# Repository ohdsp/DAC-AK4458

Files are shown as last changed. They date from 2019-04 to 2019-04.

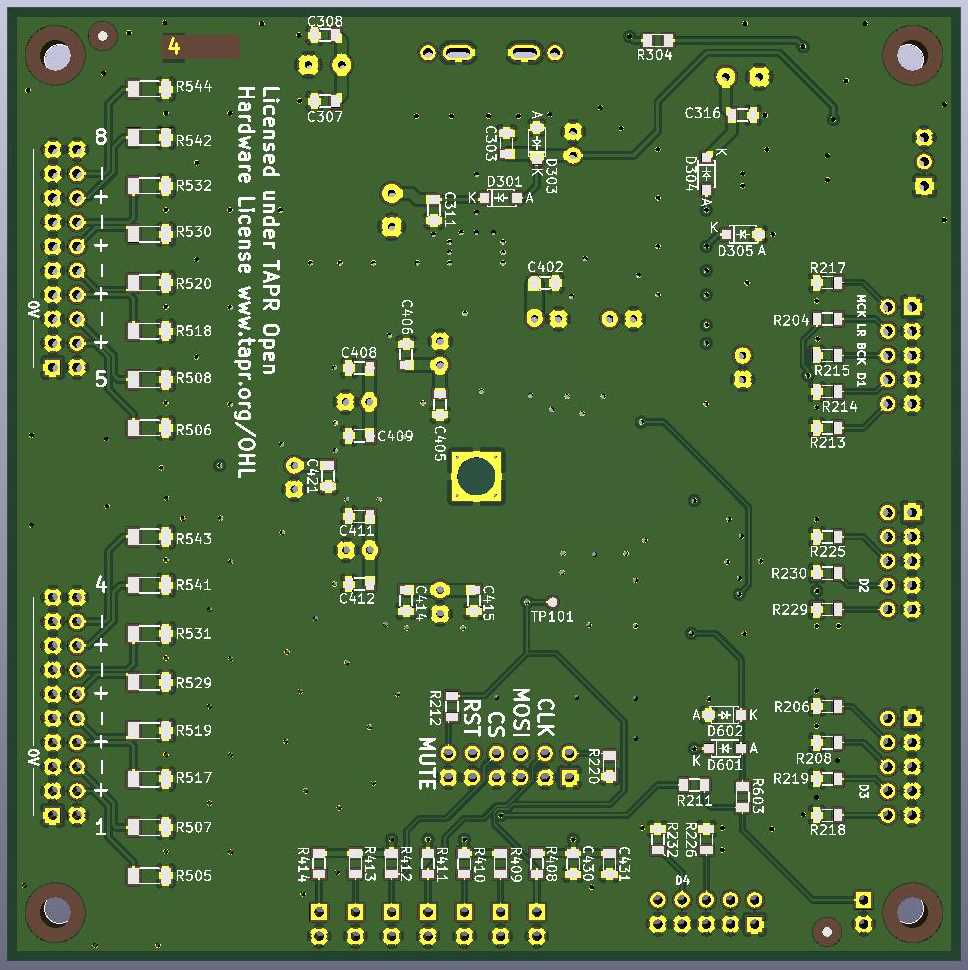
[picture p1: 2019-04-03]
JPEGs/DAC-AK4458-1.0-Bottom-small.jpg

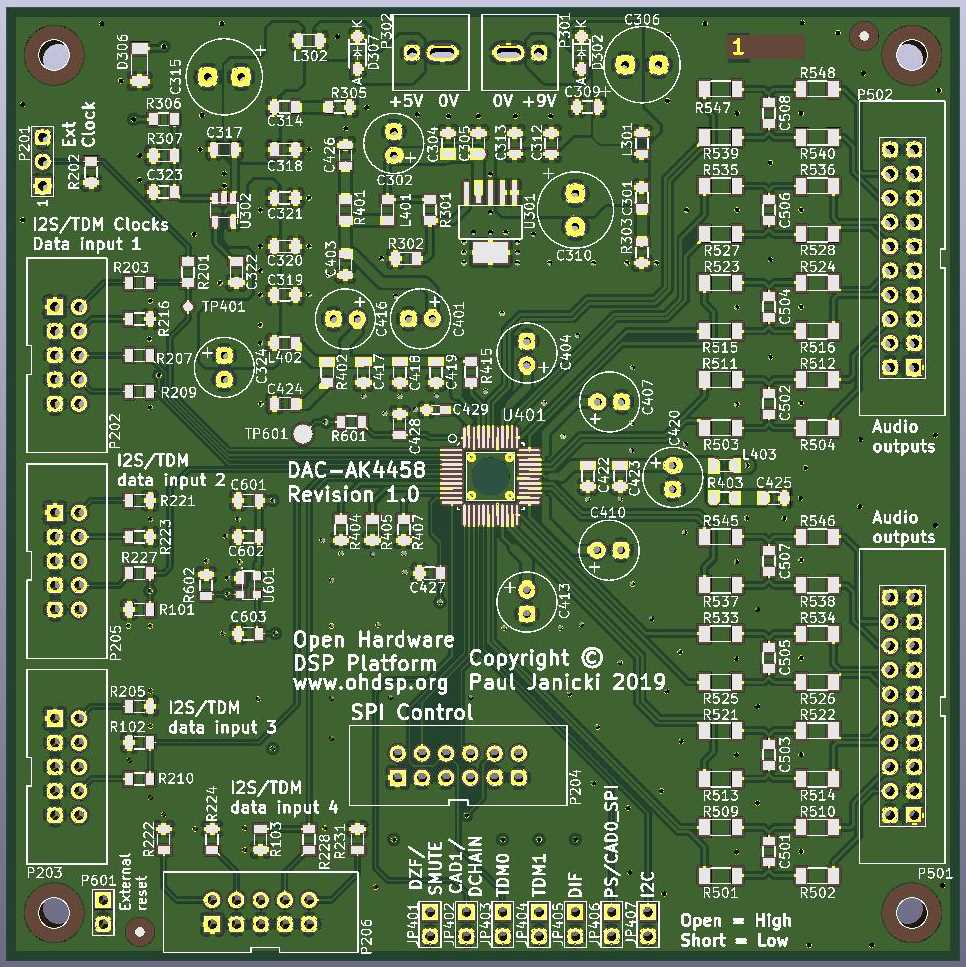
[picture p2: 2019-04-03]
JPEGs/DAC-AK4458-1.0-Front-small.jpg

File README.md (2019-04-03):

# [Open Hardware DSP Platform](http://www.ohdsp.org)
## DAC-AK4458
### Revision 1.0
### 8 Differential DAC Output Board

---
# README
### Disclaimer
Copyright Paul Janicki 2019

Licensed under the TAPR Open Hardware License (www.tapr.org/OHL)

This documentation is distributed WITHOUT ANY EXPRESS OR IMPLIED WARRANTY, INCLUDING OF MERCHANTABILITY, SATISFACTORY QUALITY AND FITNESS FOR A PARTICULAR PURPOSE.

### What is this repository?

**Quick summary**

This is Open Hardware DSP Platform DAC-AK4458 Revision 1.0. 

This is an 8 differential outputb DAC board based on the AK4458.

This repository contains the KiCad design files, manufacturing Gerber/drill files, PDF/drawing files, and relevant documenation for this board.

### What is the project folder structure?
Most folder names are self explanatory. Starting from the top level: \
*DAC-AK4458*
+ *Bill of Materials*  - This contains the bill of materials in CVS, LibreOffice Calc and XML formats
+ *Drawings* - This contains PDF and SVG Schematic and PCB files
+ *Gerbers* - This contains the PCB Gerbers and drill drawings for manufacture, there is also a zip file ready to send to most manufacturers
+ *JPEGs* - JPEGs of top and bottom views from 3D viewer
+ *KiCad* - This contains the original KiCad schematic and PCB design files
+ *Pick and Place* - This contains pick and place files for top and bottom sides
### How do I get set up?

**Summary of set up**

1. Set your self up a directory on a local disk, something simple will make life easier (eg C:\Electronics on Windows as used here), but anywhere will do just fine.
2. Download the Kicad-Libs from [https://github.com/ohdsp/KiCad-Libs](https://github.com/ohdsp/KiCad-Libs) and place in C:\Electronics\Kicad-Libs (or your chosen folder) 
3. Create a OHDSP subdirectory in C:\Electronics (so C:\Electronics\OHDSP)
3. Download this project to C:\Electronics\OHDSP\DAC-AK4458
4. Fire up Kicad
5. Open the main project file C:\Electronics\OHDSP\DAC-AK4458\KiCad\DAC-AK4458-1.0.pro
7. Do as you wish with the project, just keep it under the TAPR Open Hardware License.
Note: For library issues see below.

Make sure your git setup doesn't exclude files used in the project (like .LIB files) or things may go wrong down the line.

**KiCad Library Configuration**

Note that libraries are setup using relative paths, if you follow the above instructions things should work just fine. Below is the default library setup.

To setup eeschema component libraries:
From KiCad main window go to menu Tools -> Edit Schematic Symbols. In the new Window go to menu Preferences -> Manage Symbol Libraries.

On the new "Symbol Libraries" window select the "Project Specific Libraries" tab. The "Append Library" and "Remove Library" buttons can be used to add/remove enteries.
The standard setup is:

| | Active | Nickname | Library Path | Plugin Type | Options | Description |
|---|---|---|---|---|---|---|
| 1 | Ticked | power | ${KICAD_SYMBOL_DIR}/power.lib | Legacy | (blank) | (blank) |
| 2 | Ticked | MyKiCadLibs-Lib | ${KIPRJMOD}/../../../KiCad-Libs/MyKiCadLibs-Lib.lib | Legacy | (blank) | (blank) |

${KICAD_SYMBOL_DIR}  is set under the Enviromnet Variable Configuration. Close Symbol Libraries dialogue and go "Preferences" -> "Configure Paths..."

${KICAD_SYMBOL_DIR} is set to C:\Program Files\KiCad\share\kicad\library - this is the default for a KiCad install on the C drive

${KIPRJMOD} is automatically set to the location of the project (.pro file), in this example this would be C:\Electronics\OHDSP\uDSP\KiCad

To setup Pcbnew libraries:
From KiCad main window go to menu Tools -> Edit PCB Footprints. In the new Window go to menu Preferences -> Manage Symbol Libraries.

On the new "Symbol Libraries" window select the "Project Specific Libraries" tab. The "Append Library" and "Remove Library" buttons can be used to add/remove enteries.
The standard setup is:

| | Active | Nickname | Library Path | Plugin Type | Options | Description |
|---|---|---|---|---|---|---|
| 1 | Ticked | MyKiCadLibs-Footprints | ${KIPRJMOD}/../../../KiCad-Libs/MyKiCadLibs-Footprints.pretty | KiCad | (blank) | (blank) |

${KIPRJMOD} is automatically set to the location of the project (.pro file), in this example this would be C:\Electronics\OHDSP\uDSP\KiCad

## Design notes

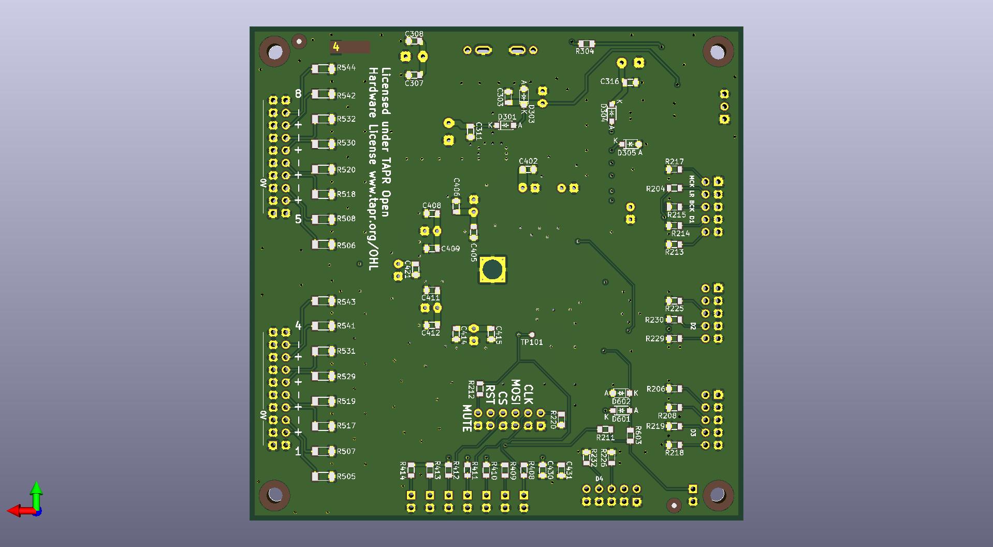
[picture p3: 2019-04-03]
JPEGs/DAC-AK4458-1.0-Bottom.jpg

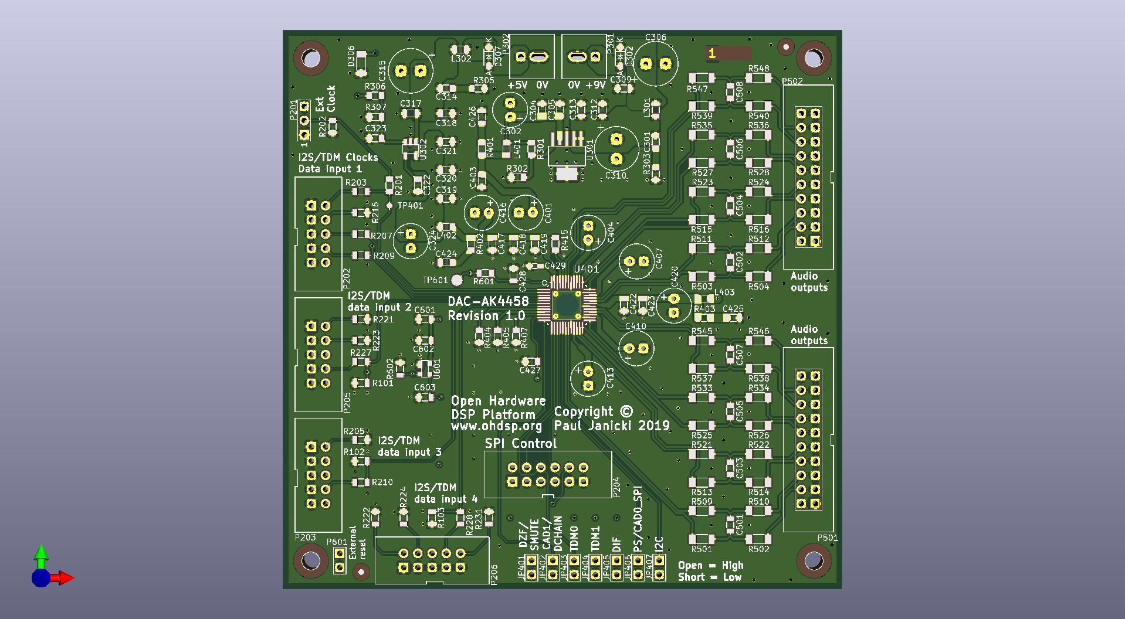
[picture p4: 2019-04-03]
JPEGs/DAC-AK4458-1.0-Front.jpg

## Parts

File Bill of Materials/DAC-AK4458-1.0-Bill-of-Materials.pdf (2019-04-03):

DAC-AK4458-1.0 Bill of Materials

### DAC-AK4458-1.0 Bill of Materials 03 April 2019

Reference | Quantity | Footprint | Value | Description | Power | Size | Tolerance Voltage | | Type | Current
C301 C314 C424 C425 C426 | 5 SMD-0805 | | 100p | 'Ceramic capacitor | ' | '0805 | '5% | '50V | 'C0G | '
C302 C324 C401 C416 C420 | 5 CAP-TH-D6.3mmP2.5mm | | 220u | 'Aluminium electrolytic low impedance capacitor - eg Panasonic FC or FR parts | ' | '2.5mm Pitch, 6.3mm Diameter | ' | '10V | ' | '
C306 C310 C315 | 3 CAP-TH-D8mmP3.5mm | | 220u | 'Aluminium electrolytic low impedance capacitor - eg Panasonic FC or FR parts | ' | '3.5mm Pitch, 8mm Diameter | ' | '25V | ' | '
C307 C311 C316 | 3 SMD-0805 | | 22u | 'Ceramic capacitor | ' | '0805 | '20% | '25V | 'X5R | '
C304 C308 C312 C317 C320 C323 C403 C405 C408 C411 C414 C418 C422 C428 C430 C602 | 16 SMD-0805 | | 100n | 'Ceramic capacitor | ' | '0805 | '10% | '50V | 'X7R | '
C305 C309 C313 C318 C321 C406 C409 C412 C415 C419 C423 C427 C603 | 13 SMD-0805 | | 10n | 'Ceramic capacitor | ' | '0805 | '10% | '50V | 'X7R | '
C303 C319 C402 C417 C421 | 5 SMD-0805 | | 22u | 'Ceramic capacitor | ' | '0805 | '20% | '10V | 'X5R | '
C322 | 1 SMD-0805 | | N/F | 'Ceramic capacitor - NOT FITTED | ' | '0805 | '10% | '50V | 'X7R | '
C404 C407 C410 C413 | 4 CAP-TH-D6.3mmP2.5mm | | 47u | 'Aluminium electrolytic low impedance capacitor - eg Panasonic FC or FR parts | ' | '2.5mm Pitch, 6.3mm Diameter | ' | '10V | ' | '
C429 | 1 SMD-0603 | | 1u | 'Ceramic capacitor | ' | '0603 | '10% | '10V | 'X7R | '
C431 C601 | 2 SMD-0805 | | 10u | 'Ceramic capacitor | ' | '0805 | '20% | '10V | 'X5R | '
C501 C502 C503 C504 C505 C506 C507 C508 | 8 SMD-0805 | | 2n7 | 'Ceramic capacitor | ' | '0805 | '5% | '50V | 'C0G | '
D301 D302 D303 D304 D305 D307 D601 D602 | 8 DIODE-SOD-123 | | 1N5819HW | '1A 40V Schottky Rectifier - SOD-123 | ' | ' | ' | ' | ' | '
D306 | 1 SMD-1206 | | Green LED 1206 | 'Green LED - SMD - Vf 1.8V to 2.2V | ' | '1206 | ' | ' | ' | '
JP401 JP402 JP403 JP404 JP405 JP406 JP407 P601 | 8 CONN_SIL_2_1MM | | CONN_2x1 | '1x2 2.54mm pitch pin header | ' | ' | ' | ' | ' | '
L301 L302 L401 L402 L403 | 5 SMD-0805 | | 600R@100MHz | 'Ferrite bead, current rating 0.3A or higher, 600R@100MHz | ' | '0805 | ' | ' | ' | '=>0.3A
P201 | 1 CONN_SIL_3_1MM | | CONN_3x1 | '1x3 2.54mm pitch pin header | ' | ' | ' | ' | ' | '
P202 P203 P205 P206 | 4 CONN_DIL_2X5_BOX_1MM | | CONN_02X05 | '2x5 2.54mm pitch box header | ' | ' | ' | ' | ' | '
P204 | 1 CONN_DIL_2X6_BOX_1MM | | CONN_02X06 | '2x6 2.54mm pitch box header | ' | ' | ' | ' | ' | '
P301 P302 | 2 CONN-2WAY-2.54mm-3.81mm-SPACING | | CONN_2x1 | '2 way screw terminal, 2.54mm to 3.81mm pitch | ' | ' | ' | ' | ' | '
P501 P502 | 2 CONN_DIL_2X10_BOX_1MM | | CONN_02X10 | '2x10 2.54mm pitch box header | ' | ' | ' | ' | ' | '
R101 R102 R103 R213 R218 R220 R229 R231 R304 R603 | 10 SMD-0805 | | 1k | 'Thick or thin film resistor | '100mW | '0805 | '1% | ' | ' | '
R201 R202 R214 R215 R216 R217 R219 R230 R232 | 9 SMD-0805 | | N/F | 'Thick or thin film resistor | '100mW | '0805 | '1% | ' | ' | '
R203 R204 R207 R209 R210 R211 R212 R227 R228 R404 R405 R407 R415 | 13 SMD-0805 | | 0 | 'Thick or thin film resistor | '100mW | '0805 | '1% | ' | ' | '
R205 R206 R208 R221 R222 R223 R224 R225 R226 R408 R409 R410 R411 R412 R413 R414 | 16 SMD-0805 | | 10k | 'Thick or thin film resistor | '100mW | '0805 | '1% | ' | ' | '
R301 | 1 SMD-0805 | | 6k8 | 'Thick or thin film resistor | '100mW | '0805 | '1% | ' | ' | '
R302 | 1 SMD-0805 | | 2k2 | 'Thick or thin film resistor | '100mW | '0805 | '1% | ' | ' | '
R303 R305 R401 R402 R403 | 5 SMD-0805 | | 47 | 'Thick or thin film resistor | '100mW | '0805 | '1% | ' | ' | '
R306 | 1 SMD-0805 | | 10K | 'Thick or thin film resistor | '100mW | '0805 | '1% | ' | ' | '
R307 | 1 SMD-0805 | | 220K | 'Thick or thin film resistor | '100mW | '0805 | '1% | ' | ' | '
R501 R503 R509 R511 R513 R515 R521 R523 R525 R527 R533 R535 R537 R539 R545 R547 | 16 SMD-1206 | | 240 | 'MELF0204 1% =>250mW or 1206 1% =>250mW | '250mW | '1206 | '1% | ' | ' | '
R502 R504 R510 R512 R514 R516 R522 R524 R526 R528 R534 R536 R538 R540 R546 R548 | 16 SMD-1206 | | 100 | 'MELF0204 1% =>250mW or 1206 1% =>250mW | '250mW | '1206 | '1% | ' | ' | '
R505 R506 R507 R508 R517 R518 R519 R520 R529 R530 R531 R532 R541 R542 R543 R544 | 16 SMD-1206 | | 100k | 'MELF0204 1% =>250mW or 1206 1% =>250mW | '250mW | '1206 | '1% | ' | ' | '
R601 | 1 SMD-0805 | | 100 | 'Thick or thin film resistor | '100mW | '0805 | '1% | ' | ' | '
R602 | 1 SMD-0805 | | 100k | 'Thick or thin film resistor | '100mW | '0805 | '1% | ' | ' | '
U301 | 1 IC-SOT223-6 | | TPS7A4501DCQ | 'TI TPS7A4501DCQ Regulator | ' | ' | ' | ' | ' | '
U302 | 1 IC-SOT23-5 | | TLV70033DDC | 'TLV700 200-mA, Low-IQ, Low-Dropout Regulator | ' | ' | ' | ' | ' | '
U401 | 1 IC_QFN_48_5.1mmpad_HF_HS | | AK4458VN | 'AK4458 8ch Premium DAC | ' | ' | ' | ' | ' | '
U601 | 1 IC-SOT143 | | CAT811TTBI | 'CAT811/ADM811 - 4-Pin Microprocessor Power Supply Supervisor with Manual Reset - Active Low | ' | ' | ' | ' | ' | '

Licensed under the TAPR Open Hardware License (www.tapr.org/OHL)

Open Hardware DSP Platform www.ohdsp.org

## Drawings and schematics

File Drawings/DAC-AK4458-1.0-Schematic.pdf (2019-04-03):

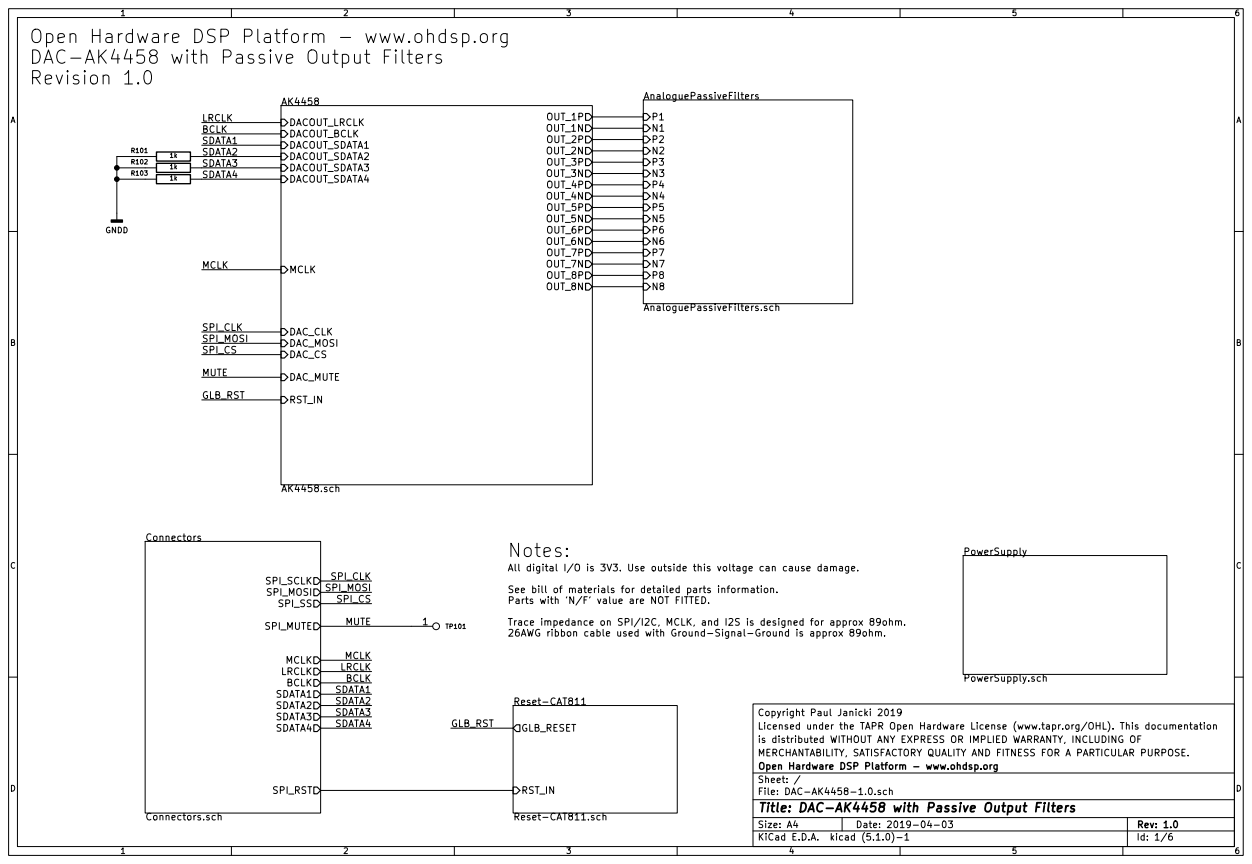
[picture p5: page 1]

AnaloguePassiveFilters.sch P1N1P2N2P3N3P4N4P5N5P6N6P7N7P8N8 Open Hardware DSP Platform - www.ohdsp.org
DAC-AK4458 with Passive Output Filters
Revision 1.0

All digital I/O is 3V3. Use outside this voltage can cause damage.

See bill of materials for detailed parts information.
Parts with 'N/F' value are NOT FITTED.

Trace impedance on SPI/I2C, MCLK, and I2S is designed for approx 89ohm.
26AWG ribbon cable used with Ground-Signal-Ground is approx 89ohm.

Copyright Paul Janicki 2019
Licensed under the TAPR Open Hardware License (www.tapr.org/OHL). This documentation
is distributed WITHOUT ANY EXPRESS OR IMPLIED WARRANTY, INCLUDING OF
MERCHANTABILITY, SATISFACTORY QUALITY AND FITNESS FOR A PARTICULAR PURPOSE.
File: DAC-AK4458-1.0.sch Sheet: / Open Hardware DSP Platform - www.ohdsp.org

Id: 1/6 Title: DAC-AK4458 with Passive Output Filters

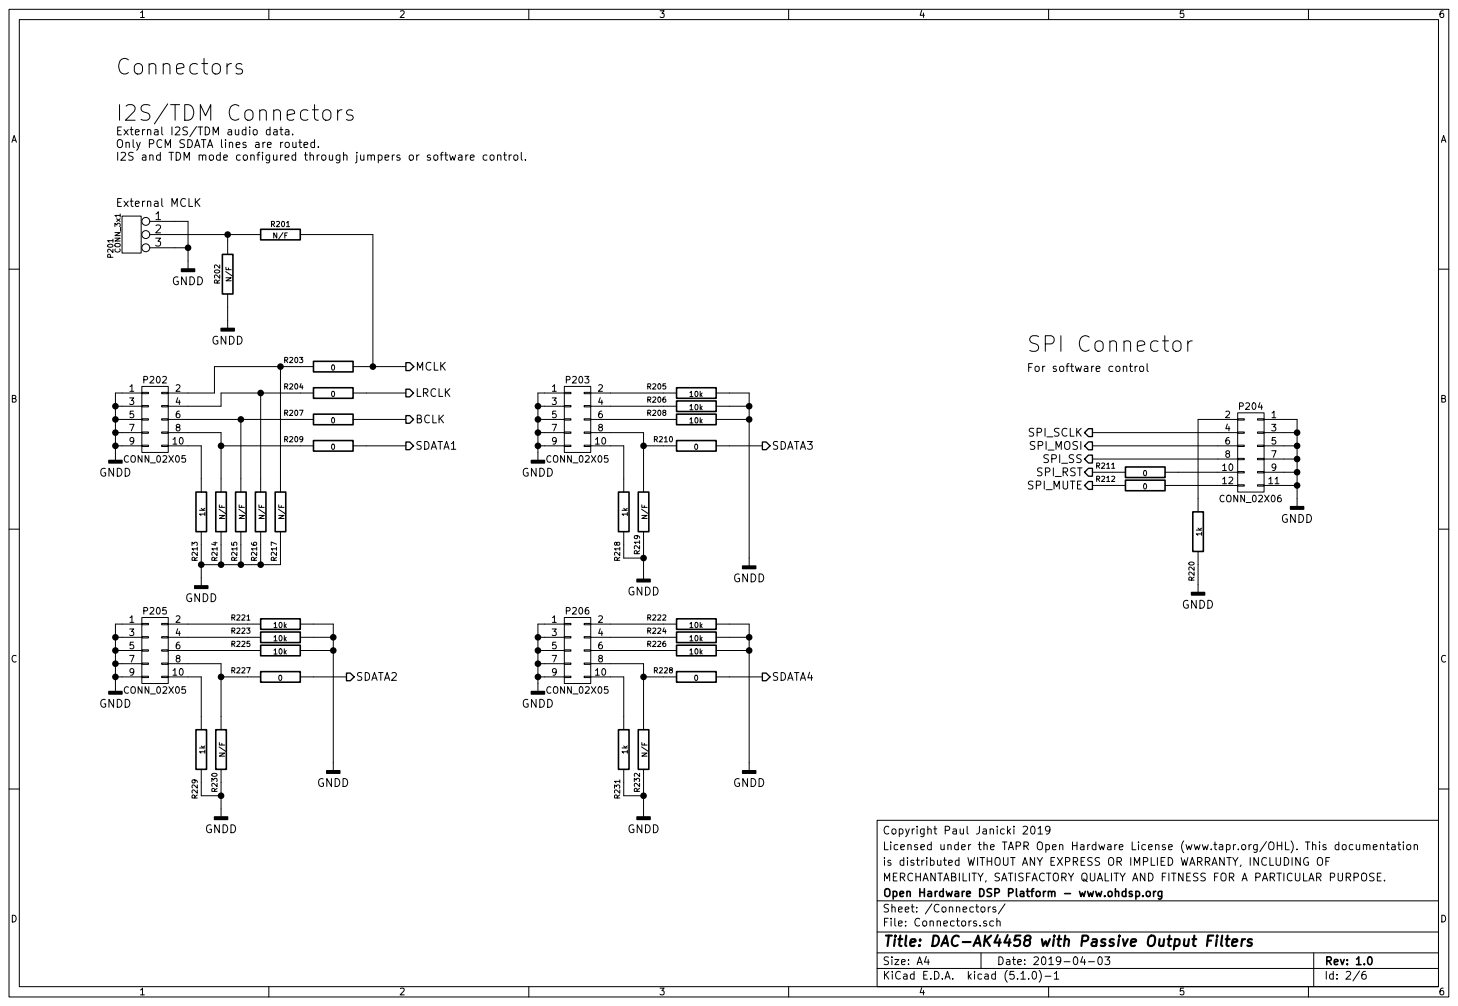
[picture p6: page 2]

I2S/TDM Connectors
External I2S/TDM audio data.
Only PCM SDATA lines are routed.
I2S and TDM mode configured through jumpers or software control.

Copyright Paul Janicki 2019
Licensed under the TAPR Open Hardware License (www.tapr.org/OHL). This documentation
is distributed WITHOUT ANY EXPRESS OR IMPLIED WARRANTY, INCLUDING OF
MERCHANTABILITY, SATISFACTORY QUALITY AND FITNESS FOR A PARTICULAR PURPOSE.
File: Connectors.sch Sheet: /Connectors/ Open Hardware DSP Platform - www.ohdsp.org

Id: 2/6 Title: DAC-AK4458 with Passive Output Filters

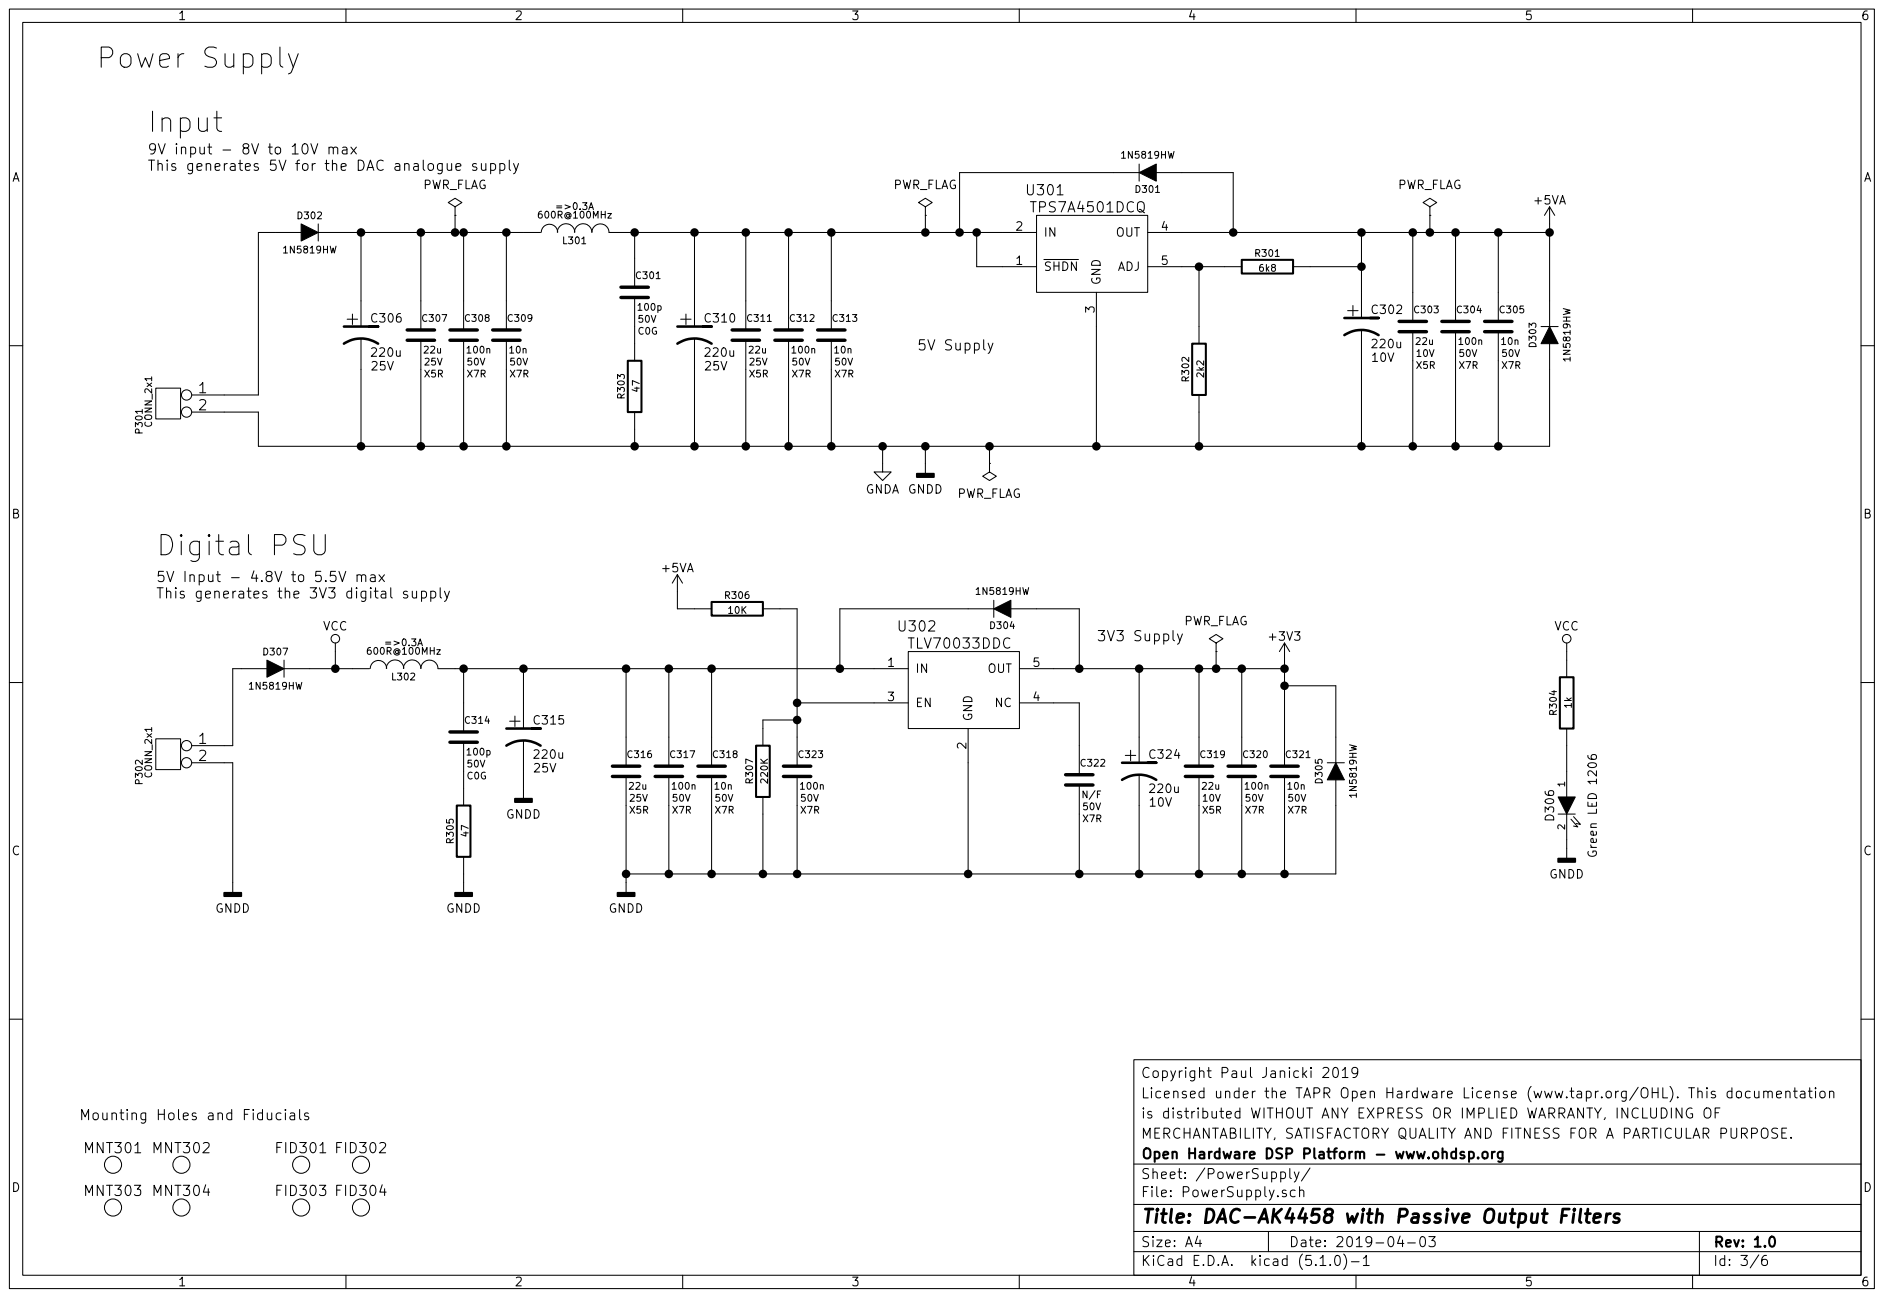
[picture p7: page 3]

9V input - 8V to 10V max
This generates 5V for the DAC analogue supply

Copyright Paul Janicki 2019 GNDA GNDD

5V Input - 4.8V to 5.5V max
This generates the 3V3 digital supply

Licensed under the TAPR Open Hardware License (www.tapr.org/OHL). This documentation
is distributed WITHOUT ANY EXPRESS OR IMPLIED WARRANTY, INCLUDING OF
MERCHANTABILITY, SATISFACTORY QUALITY AND FITNESS FOR A PARTICULAR PURPOSE.
Open Hardware DSP Platform - www.ohdsp.org
Sheet: /PowerSupply/
File: PowerSupply.sch
Id: 3/6 Title: DAC-AK4458 with Passive Output Filters

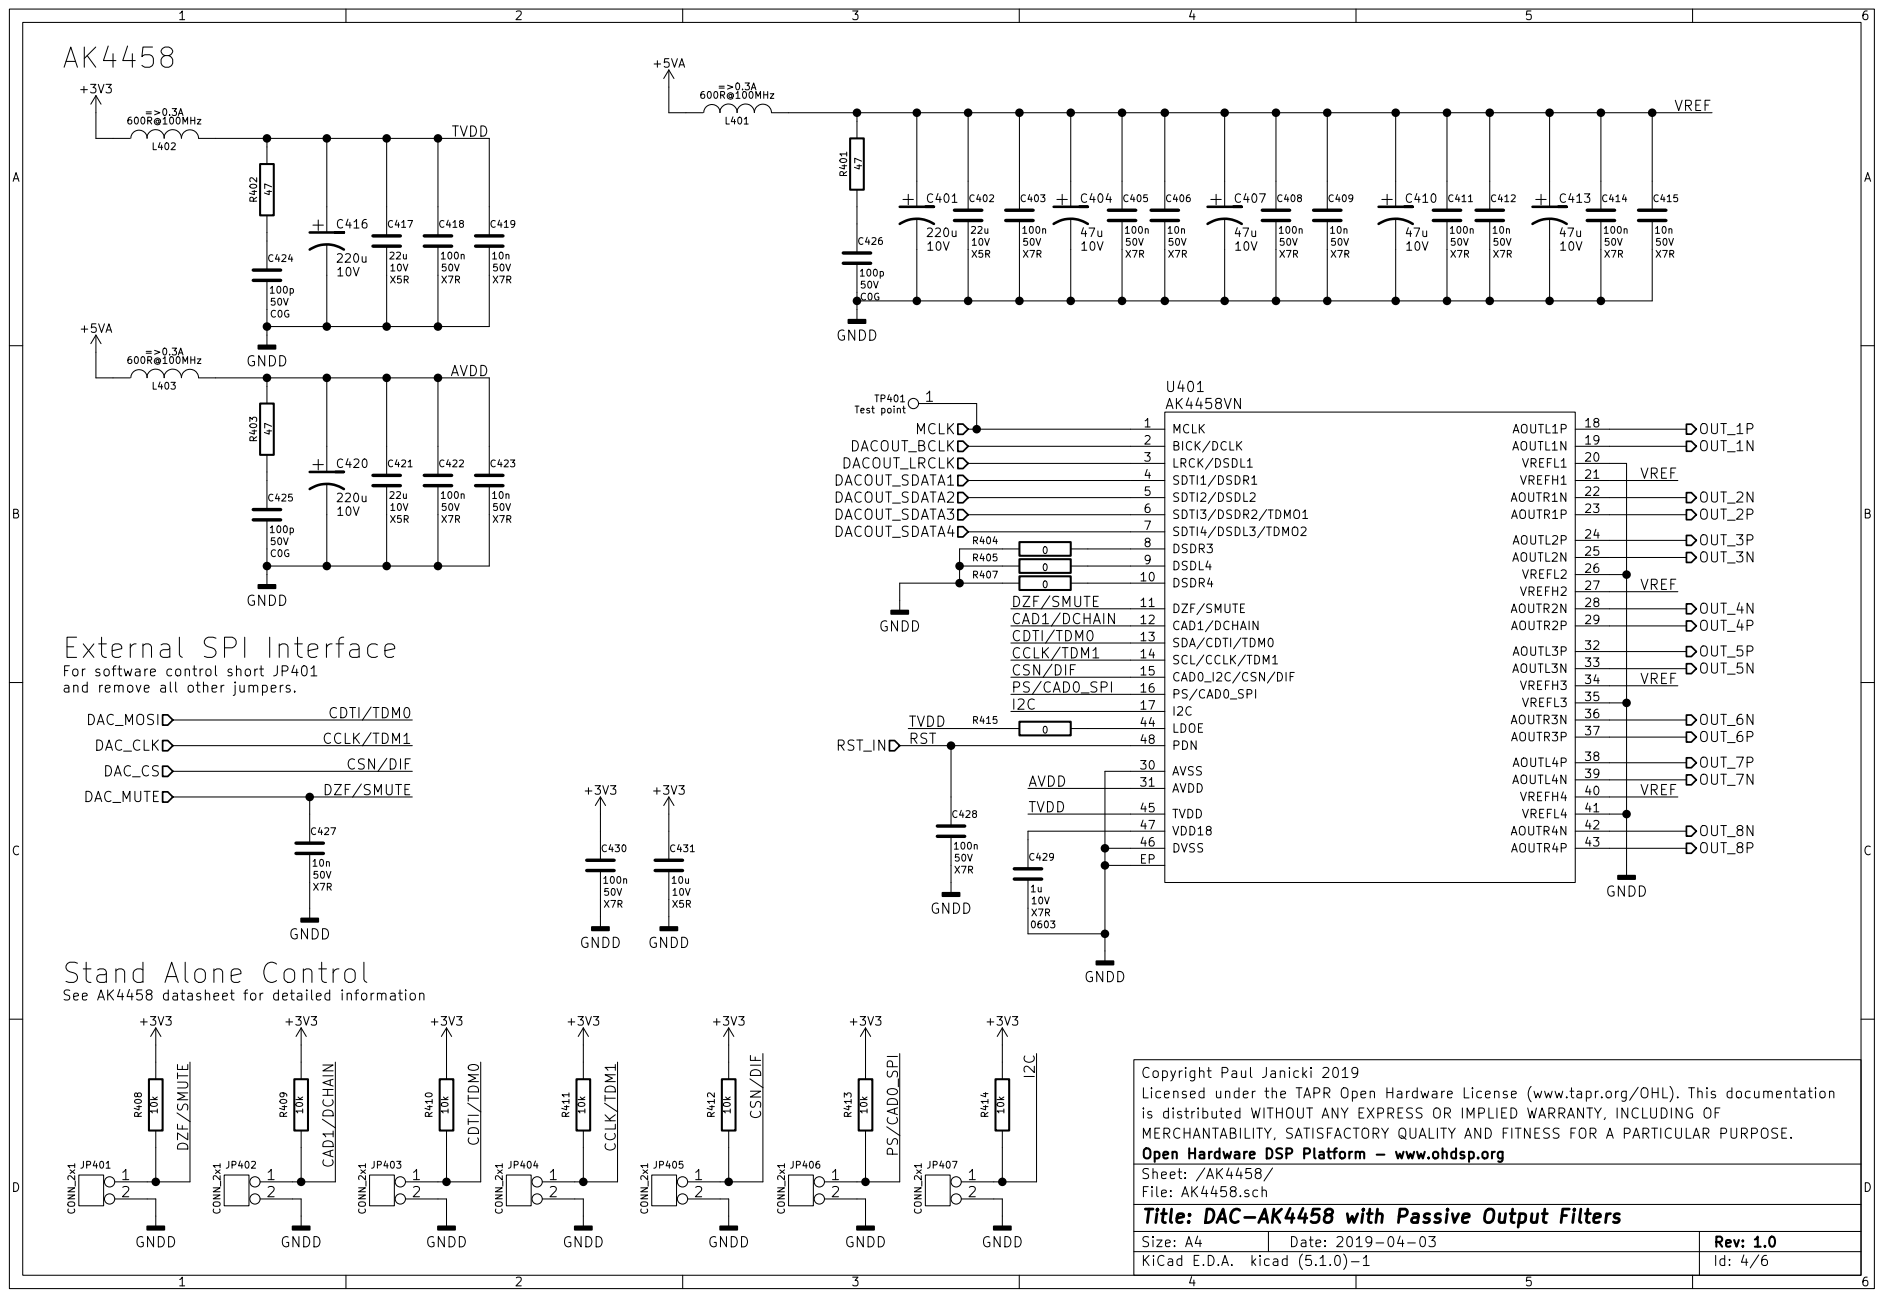
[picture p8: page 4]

VREF External SPI Interface

X7R VREF VREF VREF VREF GNDD

For software control short JP401
and remove all other jumpers.

Copyright Paul Janicki 2019
Licensed under the TAPR Open Hardware License (www.tapr.org/OHL). This documentation
is distributed WITHOUT ANY EXPRESS OR IMPLIED WARRANTY, INCLUDING OF
MERCHANTABILITY, SATISFACTORY QUALITY AND FITNESS FOR A PARTICULAR PURPOSE.
File: AK4458.sch Sheet: /AK4458/ Open Hardware DSP Platform - www.ohdsp.org

Id: 4/6 Title: DAC-AK4458 with Passive Output Filters

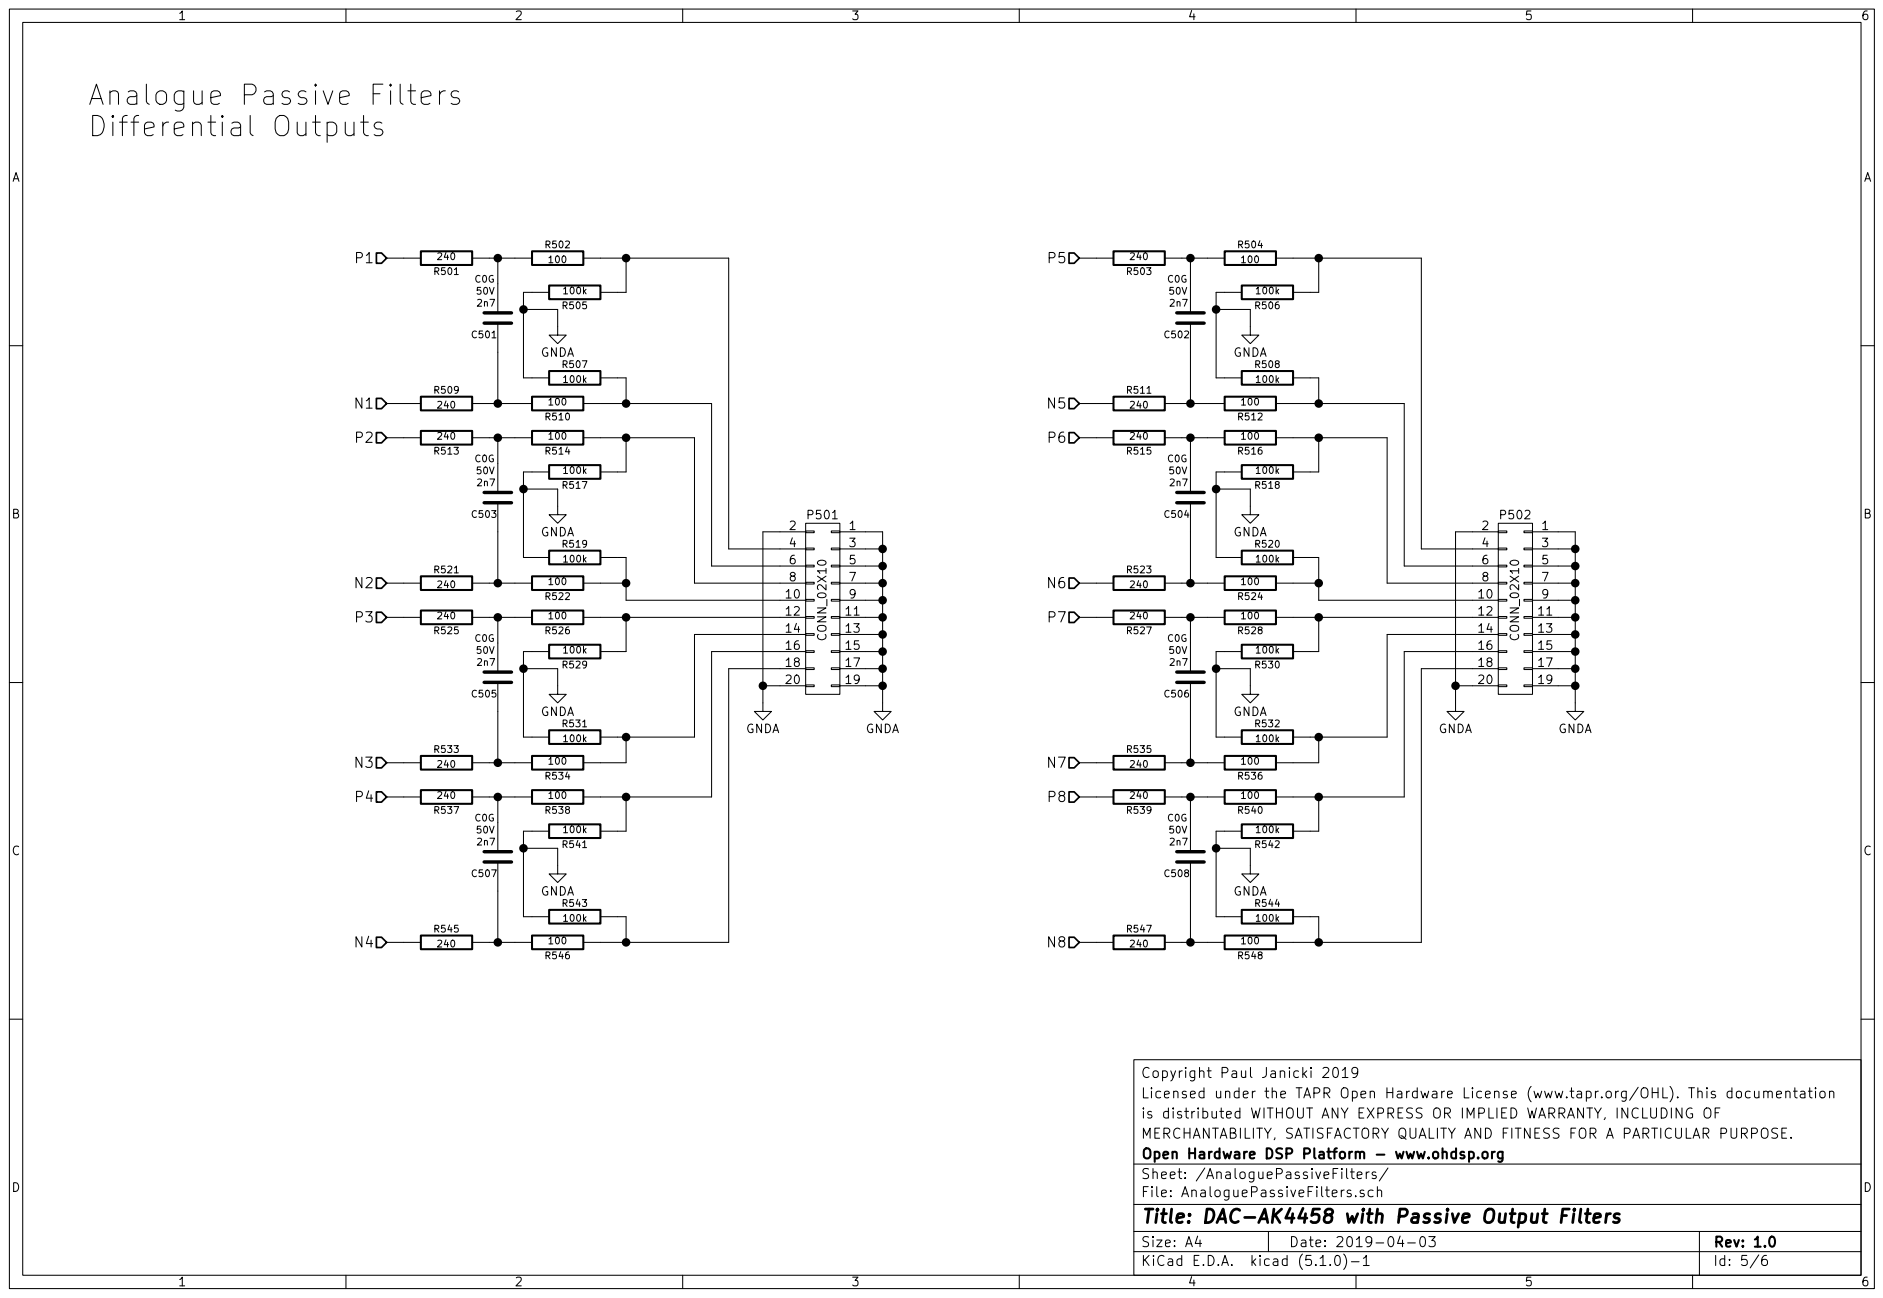
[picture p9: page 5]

Copyright Paul Janicki 2019
Licensed under the TAPR Open Hardware License (www.tapr.org/OHL). This documentation
is distributed WITHOUT ANY EXPRESS OR IMPLIED WARRANTY, INCLUDING OF
MERCHANTABILITY, SATISFACTORY QUALITY AND FITNESS FOR A PARTICULAR PURPOSE.
Open Hardware DSP Platform - www.ohdsp.org
Sheet: /AnaloguePassiveFilters/
File: AnaloguePassiveFilters.sch
Id: 5/6 Title: DAC-AK4458 with Passive Output Filters

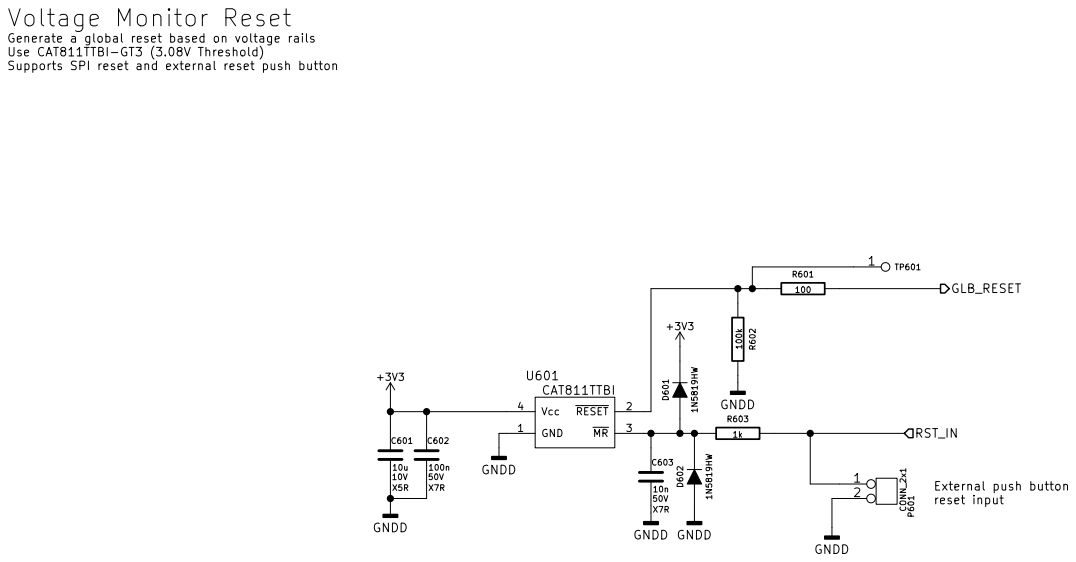
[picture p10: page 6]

Generate a global reset based on voltage rails
Use CAT811TTBIGT3 (3.08V Threshold)
Supports SPI reset and external reset push button

Copyright Paul Janicki 2019
Licensed under the TAPR Open Hardware License (www.tapr.org/OHL). This documentation
is distributed WITHOUT ANY EXPRESS OR IMPLIED WARRANTY, INCLUDING OF
MERCHANTABILITY, SATISFACTORY QUALITY AND FITNESS FOR A PARTICULAR PURPOSE.
File: Reset-CAT811.sch Sheet: /Reset-CAT811/ Open Hardware DSP Platform - www.ohdsp.org

Id: 6/6 Title: DAC-AK4458 with Passive Output Filters

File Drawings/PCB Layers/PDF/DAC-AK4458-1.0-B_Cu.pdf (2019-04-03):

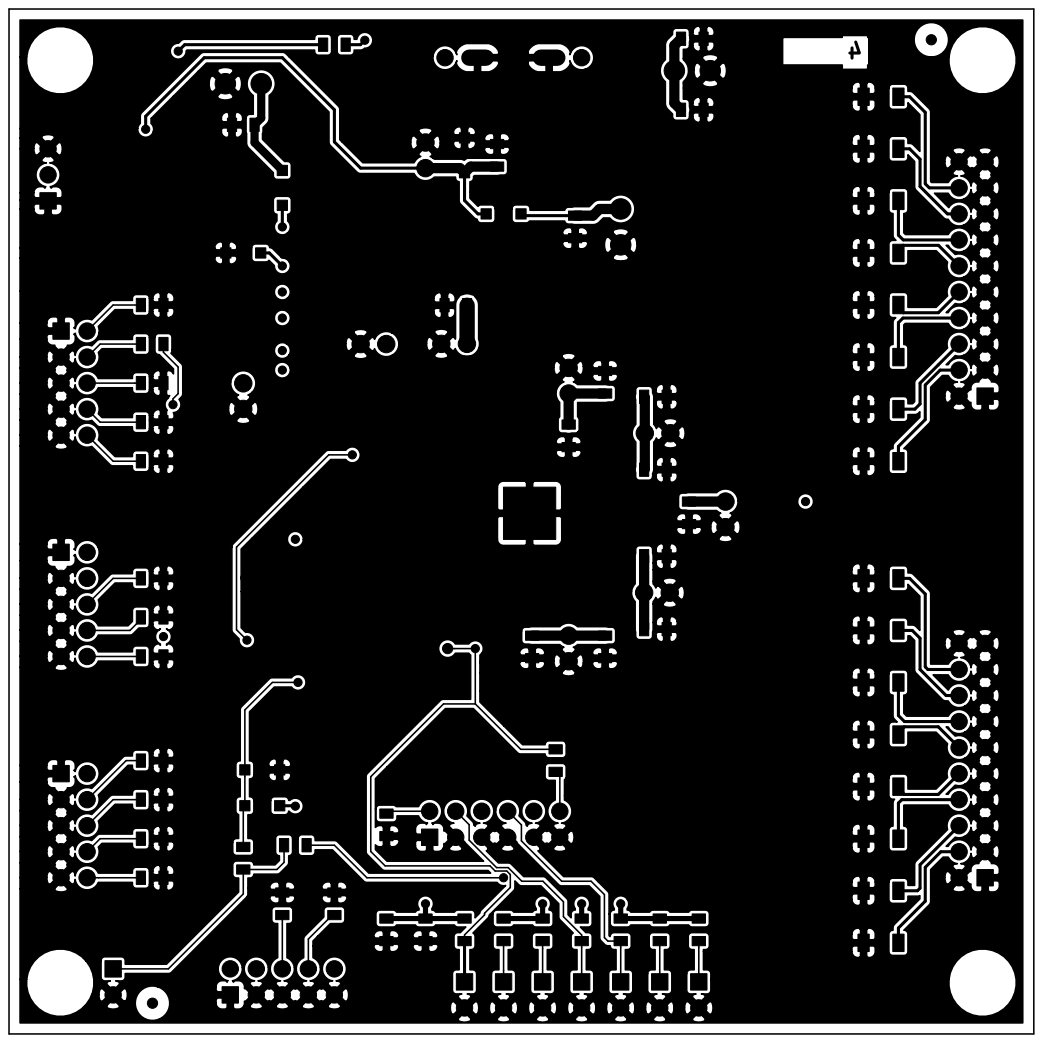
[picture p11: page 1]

Copyright Paul Janicki 2019
Licensed under the TAPR Open Hardware License (www.tapr.org/OHL). This documentation
is distributed WITHOUT ANY EXPRESS OR IMPLIED WARRANTY, INCLUDING OF
MERCHANTABILITY, SATISFACTORY QUALITY AND FITNESS FOR A PARTICULAR PURPOSE.
File: DAC-AK4458-1.0.kicad_pcb Sheet: Open Hardware DSP Platform - www.ohdsp.org

Id: 1/1 Title: DAC-AK4458 with Passive Output Filters

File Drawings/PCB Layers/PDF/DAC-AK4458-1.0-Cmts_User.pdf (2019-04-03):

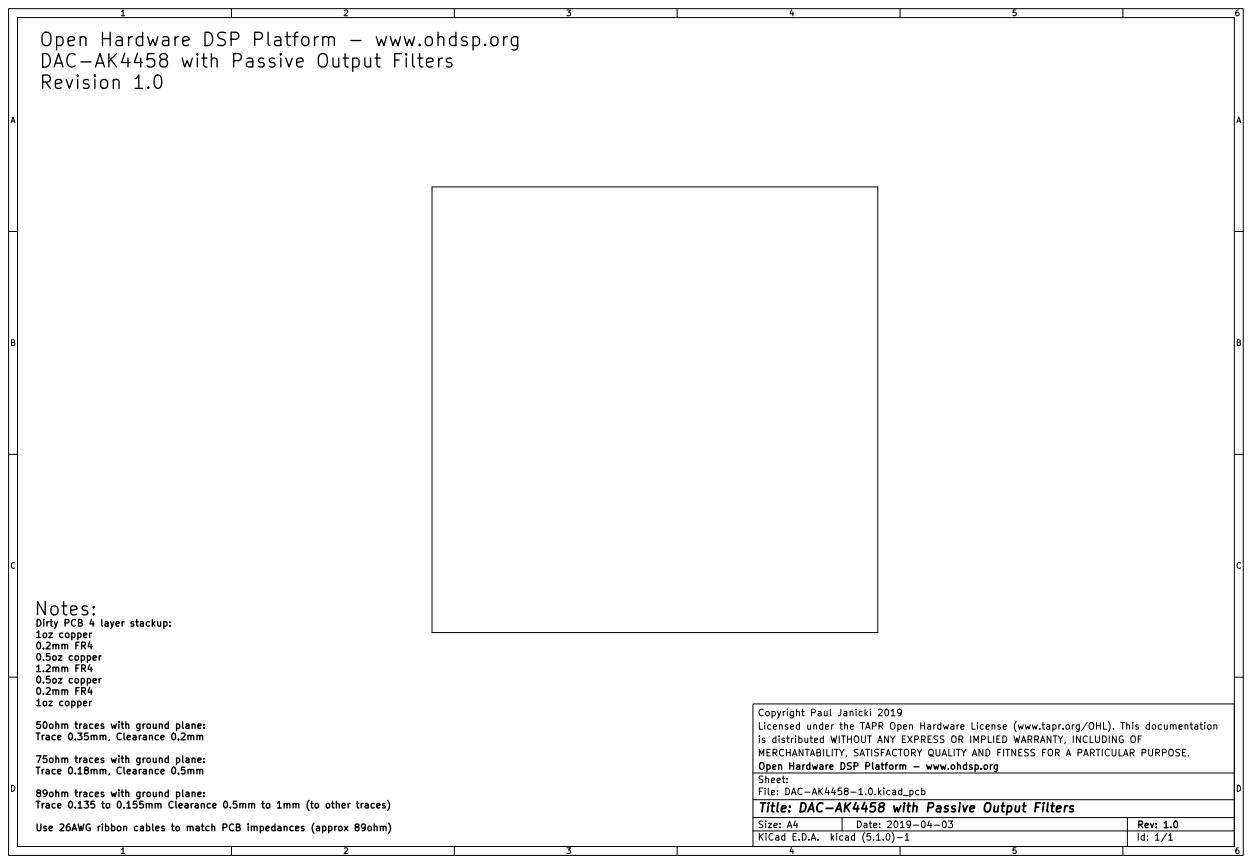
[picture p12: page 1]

Open Hardware DSP Platform - www.ohdsp.org
DAC-AK4458 with Passive Output Filters
Revision 1.0

Notes:
Dirty PCB 4 layer stackup:
1oz copper 0.2mm FR4

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

50ohm traces with ground plane:
Trace 0.35mm, Clearance 0.2mm

75ohm traces with ground plane:
Trace 0.18mm, Clearance 0.5mm

89ohm traces with ground plane:
Trace 0.135 to 0.155mm Clearance 0.5mm to 1mm (to other traces)

Id: 1/1 Title: DAC-AK4458 with Passive Output Filters

Use 26AWG ribbon cables to match PCB impedances (approx 89ohm)

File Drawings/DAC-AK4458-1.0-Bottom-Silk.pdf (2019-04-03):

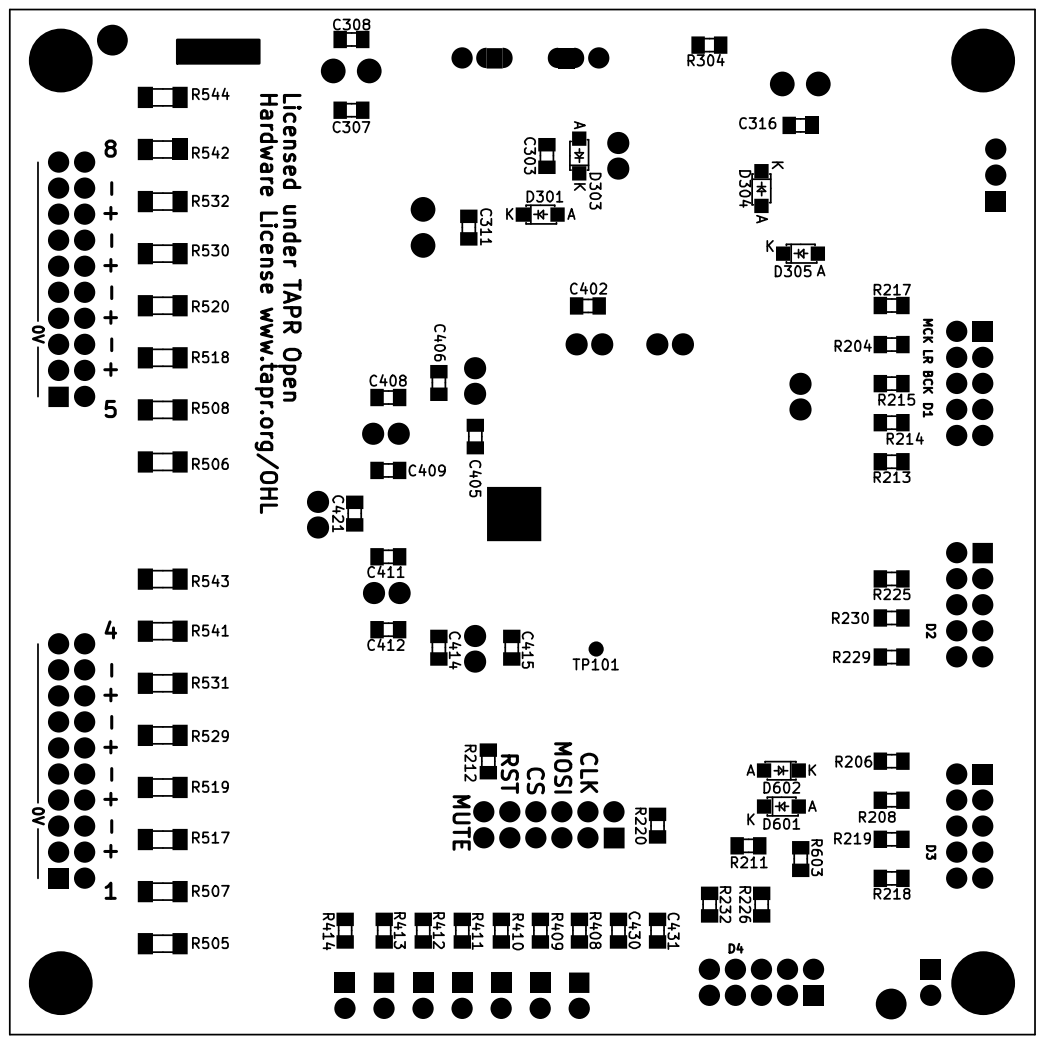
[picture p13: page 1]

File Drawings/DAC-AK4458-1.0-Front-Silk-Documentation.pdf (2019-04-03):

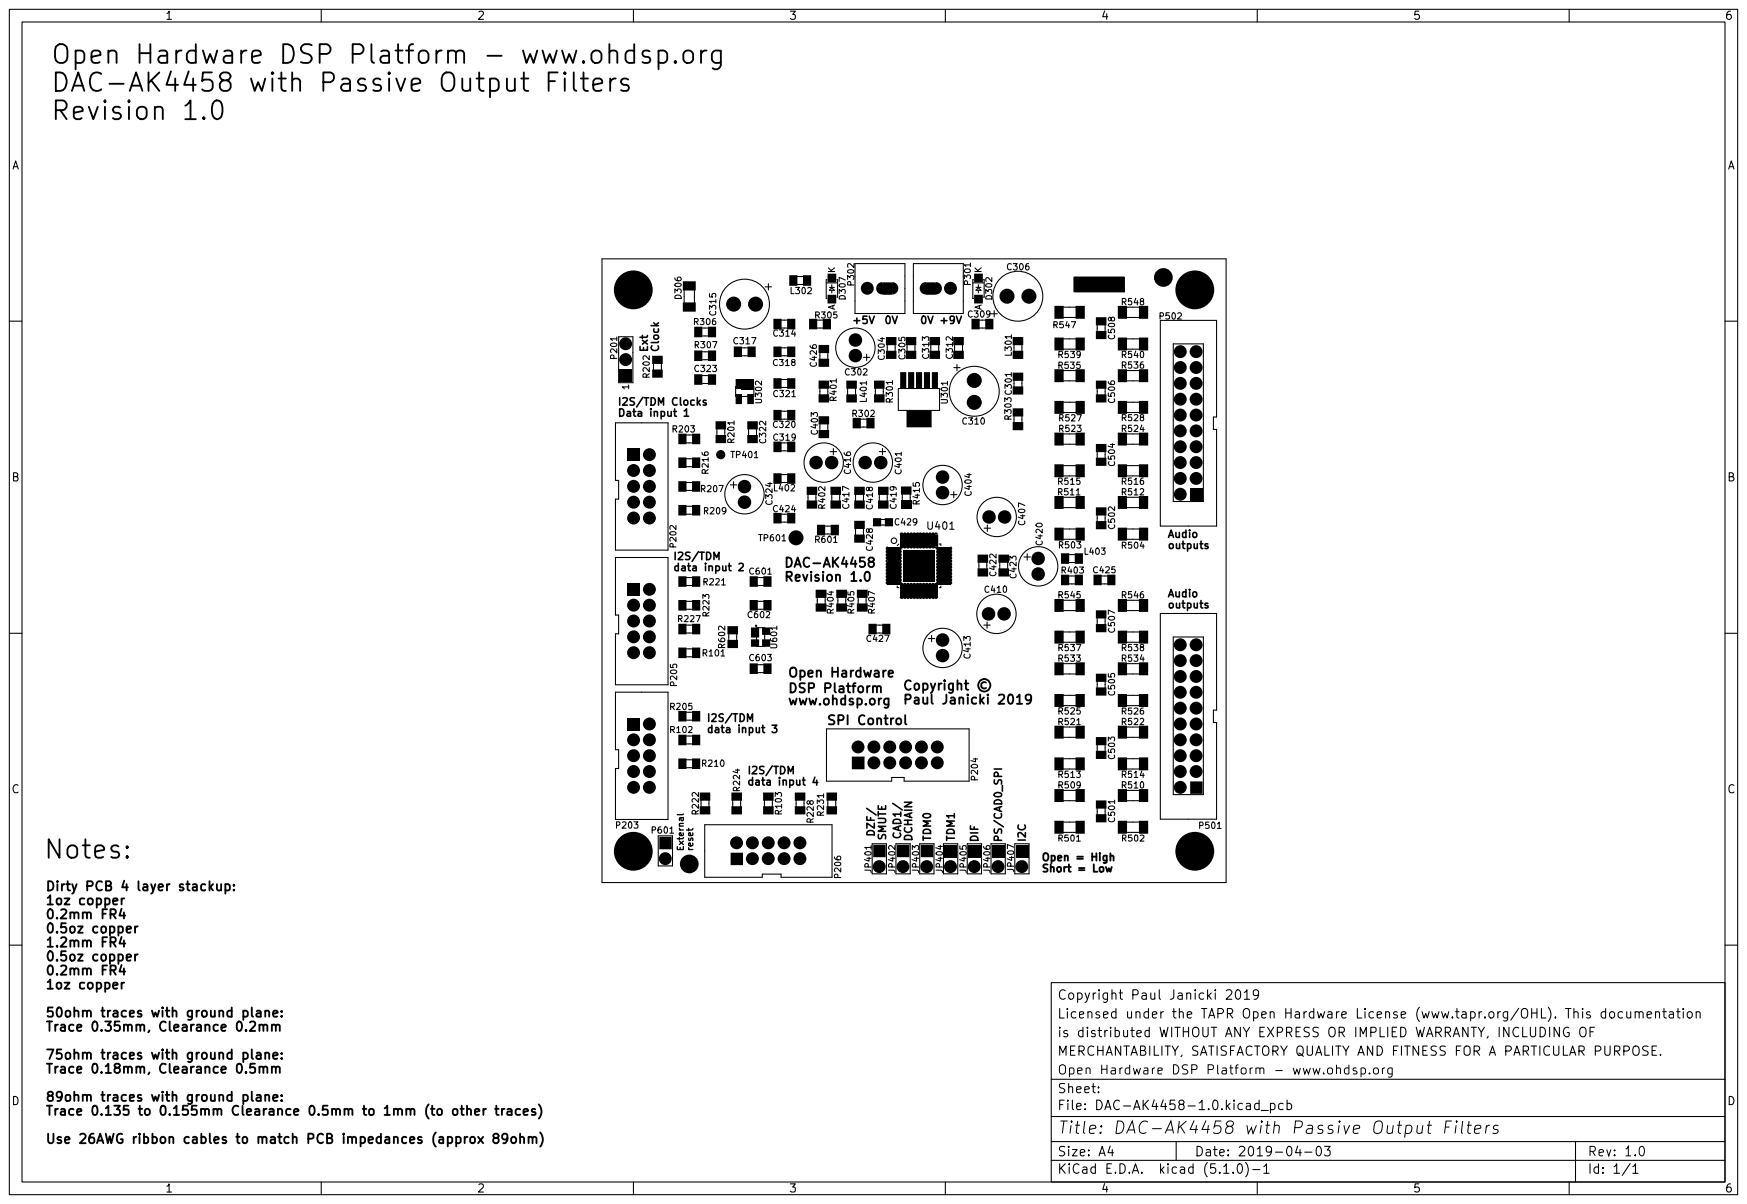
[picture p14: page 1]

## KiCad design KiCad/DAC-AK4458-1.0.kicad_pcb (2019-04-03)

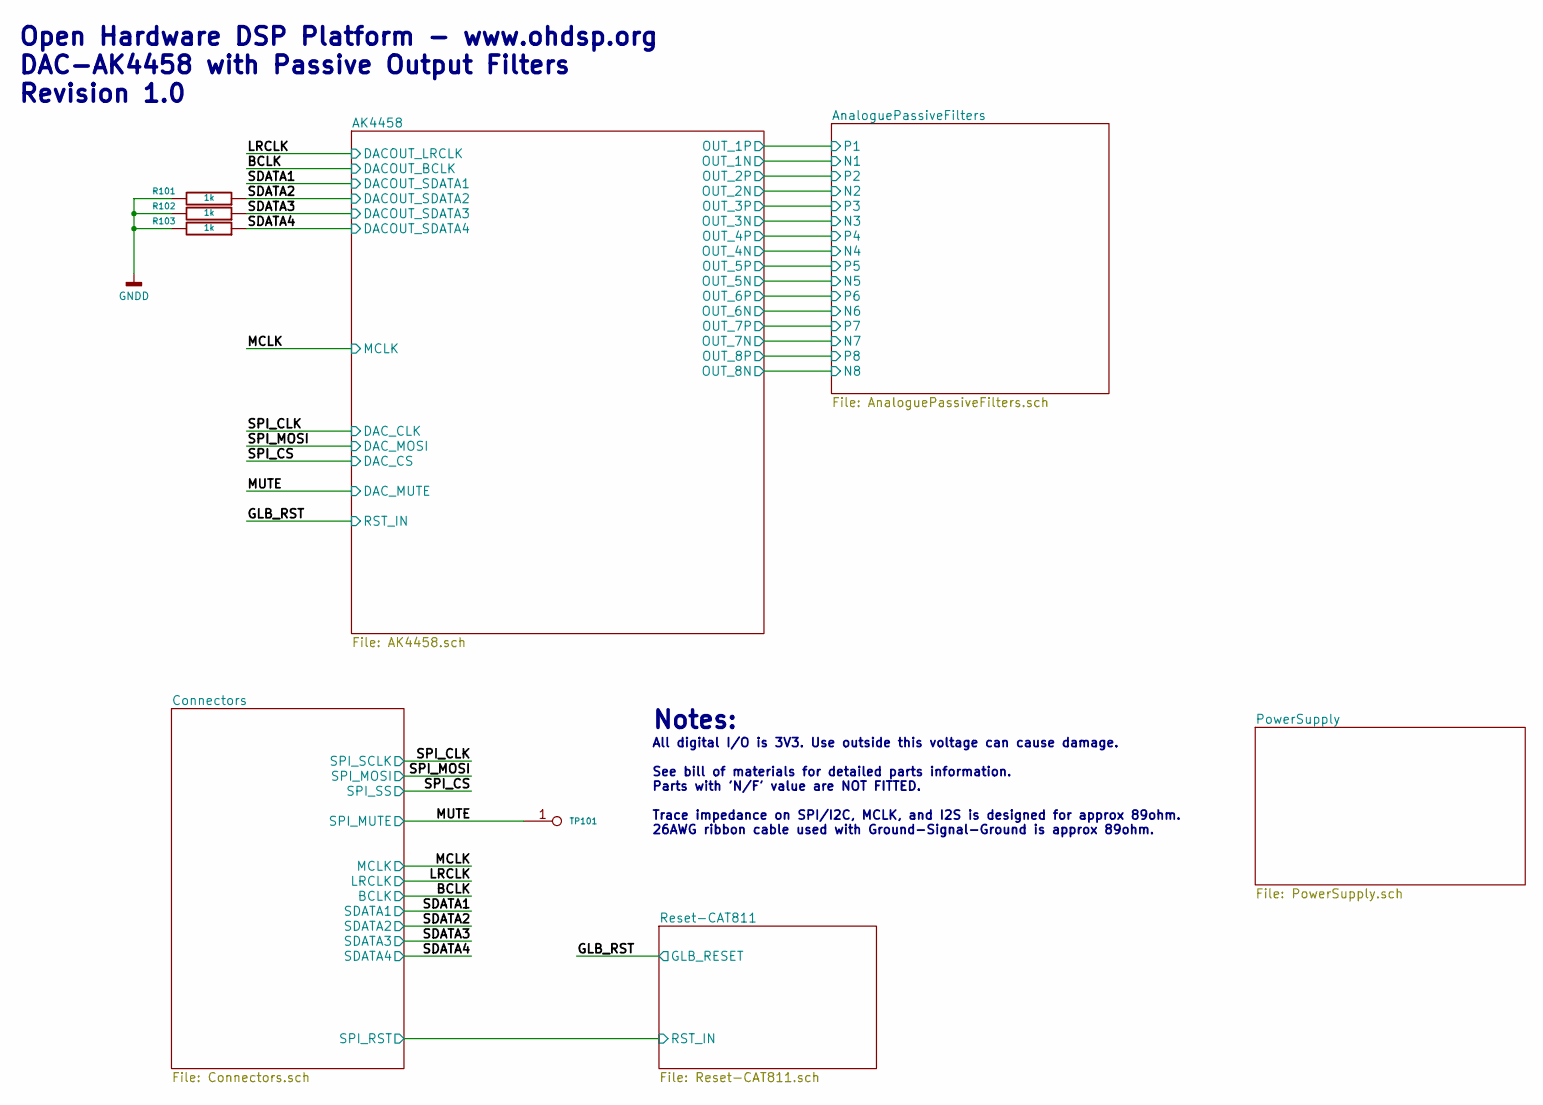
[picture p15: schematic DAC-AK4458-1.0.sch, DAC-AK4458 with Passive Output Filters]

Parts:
R101, R102, R103: 1k; SMD-0805; Tolerance 1%
TP101: Test point; TP-1mm

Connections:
/MUTE: TP101.1; also elsewhere on the board
/SDATA2: R101.1; also elsewhere on the board
/SDATA3: R102.1; also elsewhere on the board
/SDATA4: R103.1; also elsewhere on the board
GNDA: R101.2, R102.2, R103.2; also elsewhere on the board

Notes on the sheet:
Open Hardware DSP Platform - www.ohdsp.org DAC-AK4458 with Passive Output Filters Revision 1.0
All digital I/O is 3V3. Use outside this voltage can cause damage. See bill of materials for detailed parts information. Parts with 'N/F' value are NOT FITTED. Trace impedance on SPI/I2C, MCLK, and I2S is designed for approx 89ohm. 26AWG ribbon cable used with Ground-Signal-Ground is approx 89ohm.
Notes:

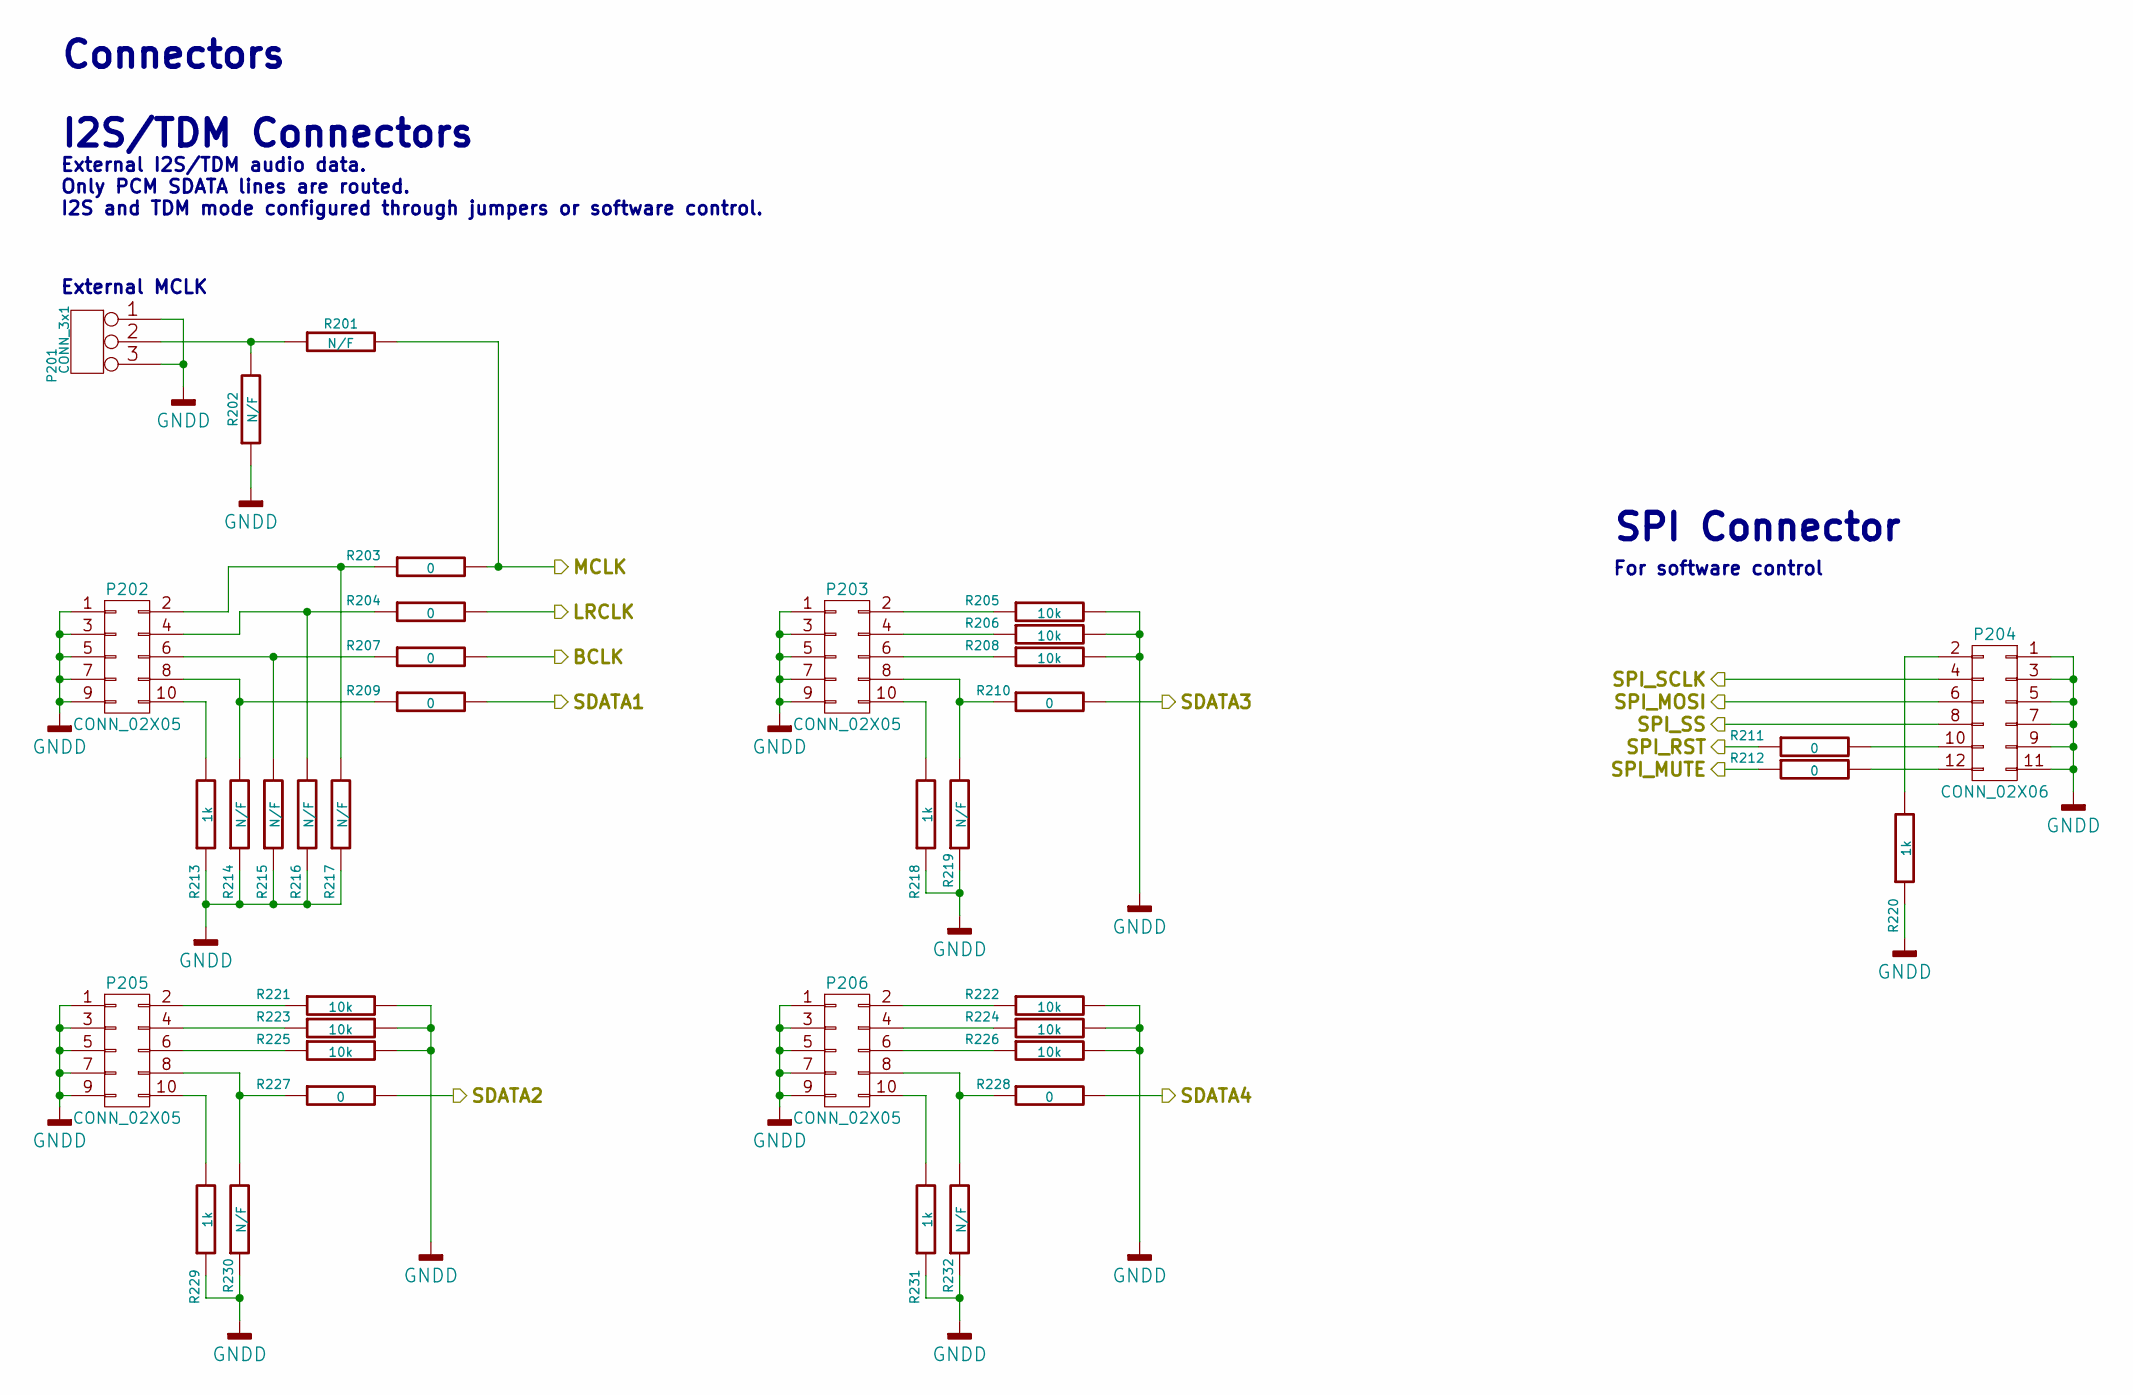
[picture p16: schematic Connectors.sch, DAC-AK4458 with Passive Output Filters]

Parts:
P201: CONN_3x1; CONN_SIL_3_1MM
P202, P203, P205, P206: CONN_02X05; CONN_DIL_2X5_BOX_1MM
P204: CONN_02X06; CONN_DIL_2X6_BOX_1MM
R201, R202, R214, R215, R216, R217, R219, R230, R232: N/F; SMD-0805; Tolerance 1%
R203, R204, R207, R209, R210, R211, R212, R227, R228: 0; SMD-0805; Tolerance 1%
R205, R206, R208, R221, R222, R223, R224, R225, R226: 10k; SMD-0805; Tolerance 1%
R213, R218, R220, R229, R231: 1k; SMD-0805; Tolerance 1%

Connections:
/BCLK: R207.2; also elsewhere on the board
/LRCLK: R204.2; also elsewhere on the board
/MCLK: R201.2, R203.2; also elsewhere on the board
/MUTE: R212.1; also elsewhere on the board
/Reset-CAT811/RST_IN: R211.1; also elsewhere on the board
/SDATA1: R209.2; also elsewhere on the board
/SDATA2: R227.2; also elsewhere on the board
/SDATA3: R210.2; also elsewhere on the board
/SDATA4: R228.2; also elsewhere on the board
/SPI_CLK: P204.4; also elsewhere on the board
/SPI_CS: P204.8; also elsewhere on the board
/SPI_MOSI: P204.6; also elsewhere on the board
GNDA: P201.1, P201.3, P202.1, P202.3, P202.5, P202.7, P202.9, P203.1, P203.3, P203.5, P203.7, P203.9, P204.1, P204.3, P204.5, P204.7, P204.9, P204.11, P205.1, P205.3, P205.5, P205.7, P205.9, P206.1, P206.3, P206.5, P206.7, P206.9, R202.1, R205.2, R206.2, R208.2, R213.1, R214.1, R215.1, R216.1, R217.1, R218.1, R219.1, R220.1, R221.2, R222.2, R223.2, R224.2, R225.2, R226.2, R229.1, R230.1, R231.1, R232.1; also elsewhere on the board
unnamed: P201.2, R201.1, R202.2
unnamed: P202.2, R203.1, R217.2
unnamed: P202.4, R204.1, R216.2
unnamed: P202.6, R207.1, R215.2
unnamed: P202.8, R209.1, R214.2
unnamed: P202.10, R213.2
unnamed: P203.2, R205.1
unnamed: P203.4, R206.1
unnamed: P203.6, R208.1
unnamed: P203.8, R210.1, R219.2
unnamed: P203.10, R218.2
unnamed: P204.2, R220.2
unnamed: P204.10, R211.2
unnamed: P204.12, R212.2
unnamed: P205.2, R221.1
unnamed: P205.4, R223.1
unnamed: P205.6, R225.1
unnamed: P205.8, R227.1, R230.2
unnamed: P205.10, R229.2
unnamed: P206.2, R222.1
unnamed: P206.4, R224.1
unnamed: P206.6, R226.1
unnamed: P206.8, R228.1, R232.2
unnamed: P206.10, R231.2

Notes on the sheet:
SPI Connector
I2S/TDM Connectors
External MCLK
External I2S/TDM audio data. Only PCM SDATA lines are routed. I2S and TDM mode configured through jumpers or software control.
For software control
Connectors

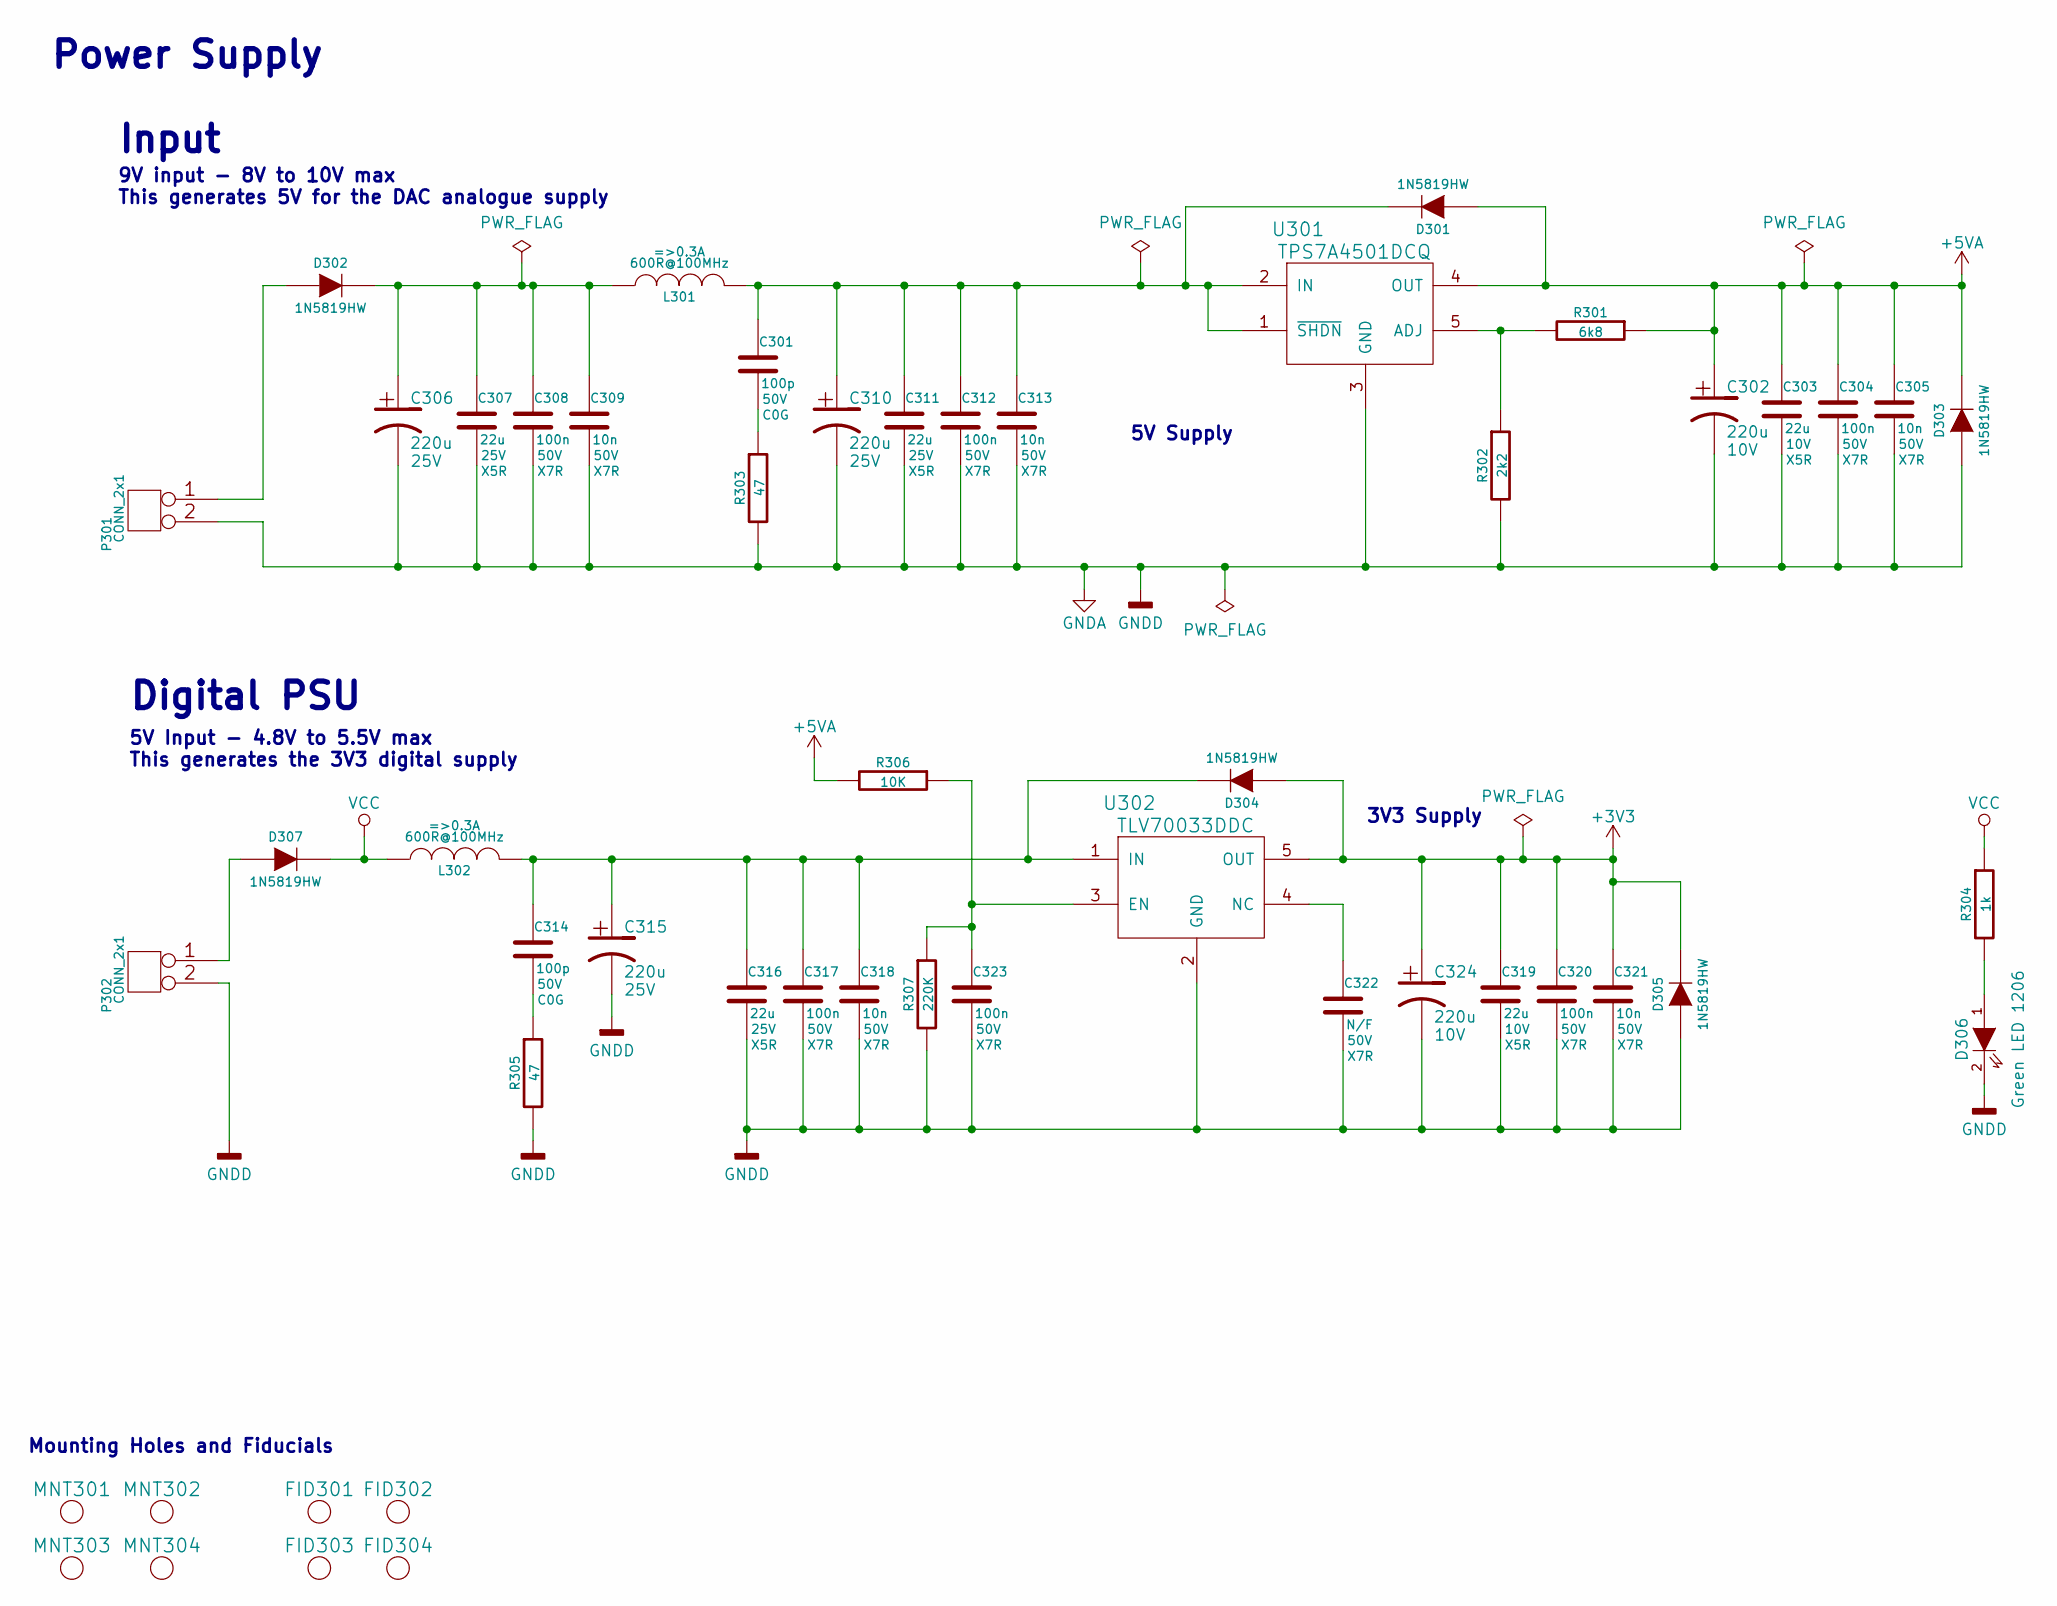
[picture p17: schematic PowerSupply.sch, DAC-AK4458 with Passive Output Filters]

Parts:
C301, C314: 100p; SMD-0805; Voltage 50V; Tolerance 5%
C302, C324: 220u; CAP-TH-D6.3mmP2.5mm; Voltage 10V
C303, C319: 22u; SMD-0805; Voltage 10V; Tolerance 20%
C304, C308, C312, C317, C320, C323: 100n; SMD-0805; Voltage 50V; Tolerance 10%
C305, C309, C313, C318, C321: 10n; SMD-0805; Voltage 50V; Tolerance 10%
C306, C310, C315: 220u; CAP-TH-D8mmP3.5mm; Voltage 25V
C307, C311, C316: 22u; SMD-0805; Voltage 25V; Tolerance 20%
C322: N/F; SMD-0805; Voltage 50V; Tolerance 10%
D301, D302, D303, D304, D305, D307: 1N5819HW; DIODE-SOD-123
D306: Green LED 1206; SMD-1206
FID301, FID302, FID303, FID304: MNT_HOLE; FID-1MM-3MM
L301, L302: 600R@100MHz; SMD-0805
MNT301, MNT302, MNT303, MNT304: MNT_HOLE; MNT_HOLE_3.2mm
P301, P302: CONN_2x1; CONN-2WAY-2.54mm-3.81mm-SPACING
R301: 6k8; SMD-0805; Tolerance 1%
R302: 2k2; SMD-0805; Tolerance 1%
R303, R305: 47; SMD-0805; Tolerance 1%
R304: 1k; SMD-0805; Tolerance 1%
R306: 10K; SMD-0805; Tolerance 1%
R307: 220K; SMD-0805; Tolerance 1%
U301: TPS7A4501DCQ; IC-SOT223-6
U302: TLV70033DDC; IC-SOT23-5

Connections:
+3V3: C319.1, C320.1, C321.1, C324.1, D304.1 (A), D305.2 (K), U302.5 (OUT); also elsewhere on the board
+5VA: C302.1, C303.1, C304.1, C305.1, D301.1 (A), D303.2 (K), R301.1, R306.2, U301.4 (OUT); also elsewhere on the board
GNDA: C302.2, C303.2, C304.2, C305.2, C306.2, C307.2, C308.2, C309.2, C310.2, C311.2, C312.2, C313.2, C315.2, C316.2, C317.2, C318.2, C319.2, C320.2, C321.2, C322.2, C323.2, C324.2, D303.1 (A), D305.1 (A), D306.2 (K), P301.2, P302.2, R302.2, R303.2, R305.2, R307.2, U301.3 (GND), U302.2 (GND); also elsewhere on the board
unnamed: C301.1, C310.1, C311.1, C312.1, C313.1, D301.2 (K), L301.2, U301.1 (~SHDN), U301.2 (IN)
unnamed: C301.2, R303.1
unnamed: C306.1, C307.1, C308.1, C309.1, D302.2 (K), L301.1
unnamed: C314.1, C315.1, C316.1, C317.1, C318.1, D304.2 (K), L302.2, U302.1 (IN)
unnamed: C314.2, R305.1
unnamed: C322.1, U302.4 (NC)
unnamed: C323.1, R306.1, R307.1, U302.3 (EN)
unnamed: D302.1 (A), P301.1
unnamed: D306.1 (A), R304.2
unnamed: D307.1 (A), P302.1
unnamed: R301.2, R302.1, U301.5 (ADJ)
VCC: D307.2 (K), L302.1, R304.1

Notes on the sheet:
Mounting Holes and Fiducials
Input
Digital PSU
9V input - 8V to 10V max This generates 5V for the DAC analogue supply
5V Input - 4.8V to 5.5V max This generates the 3V3 digital supply
5V Supply
3V3 Supply
Power Supply

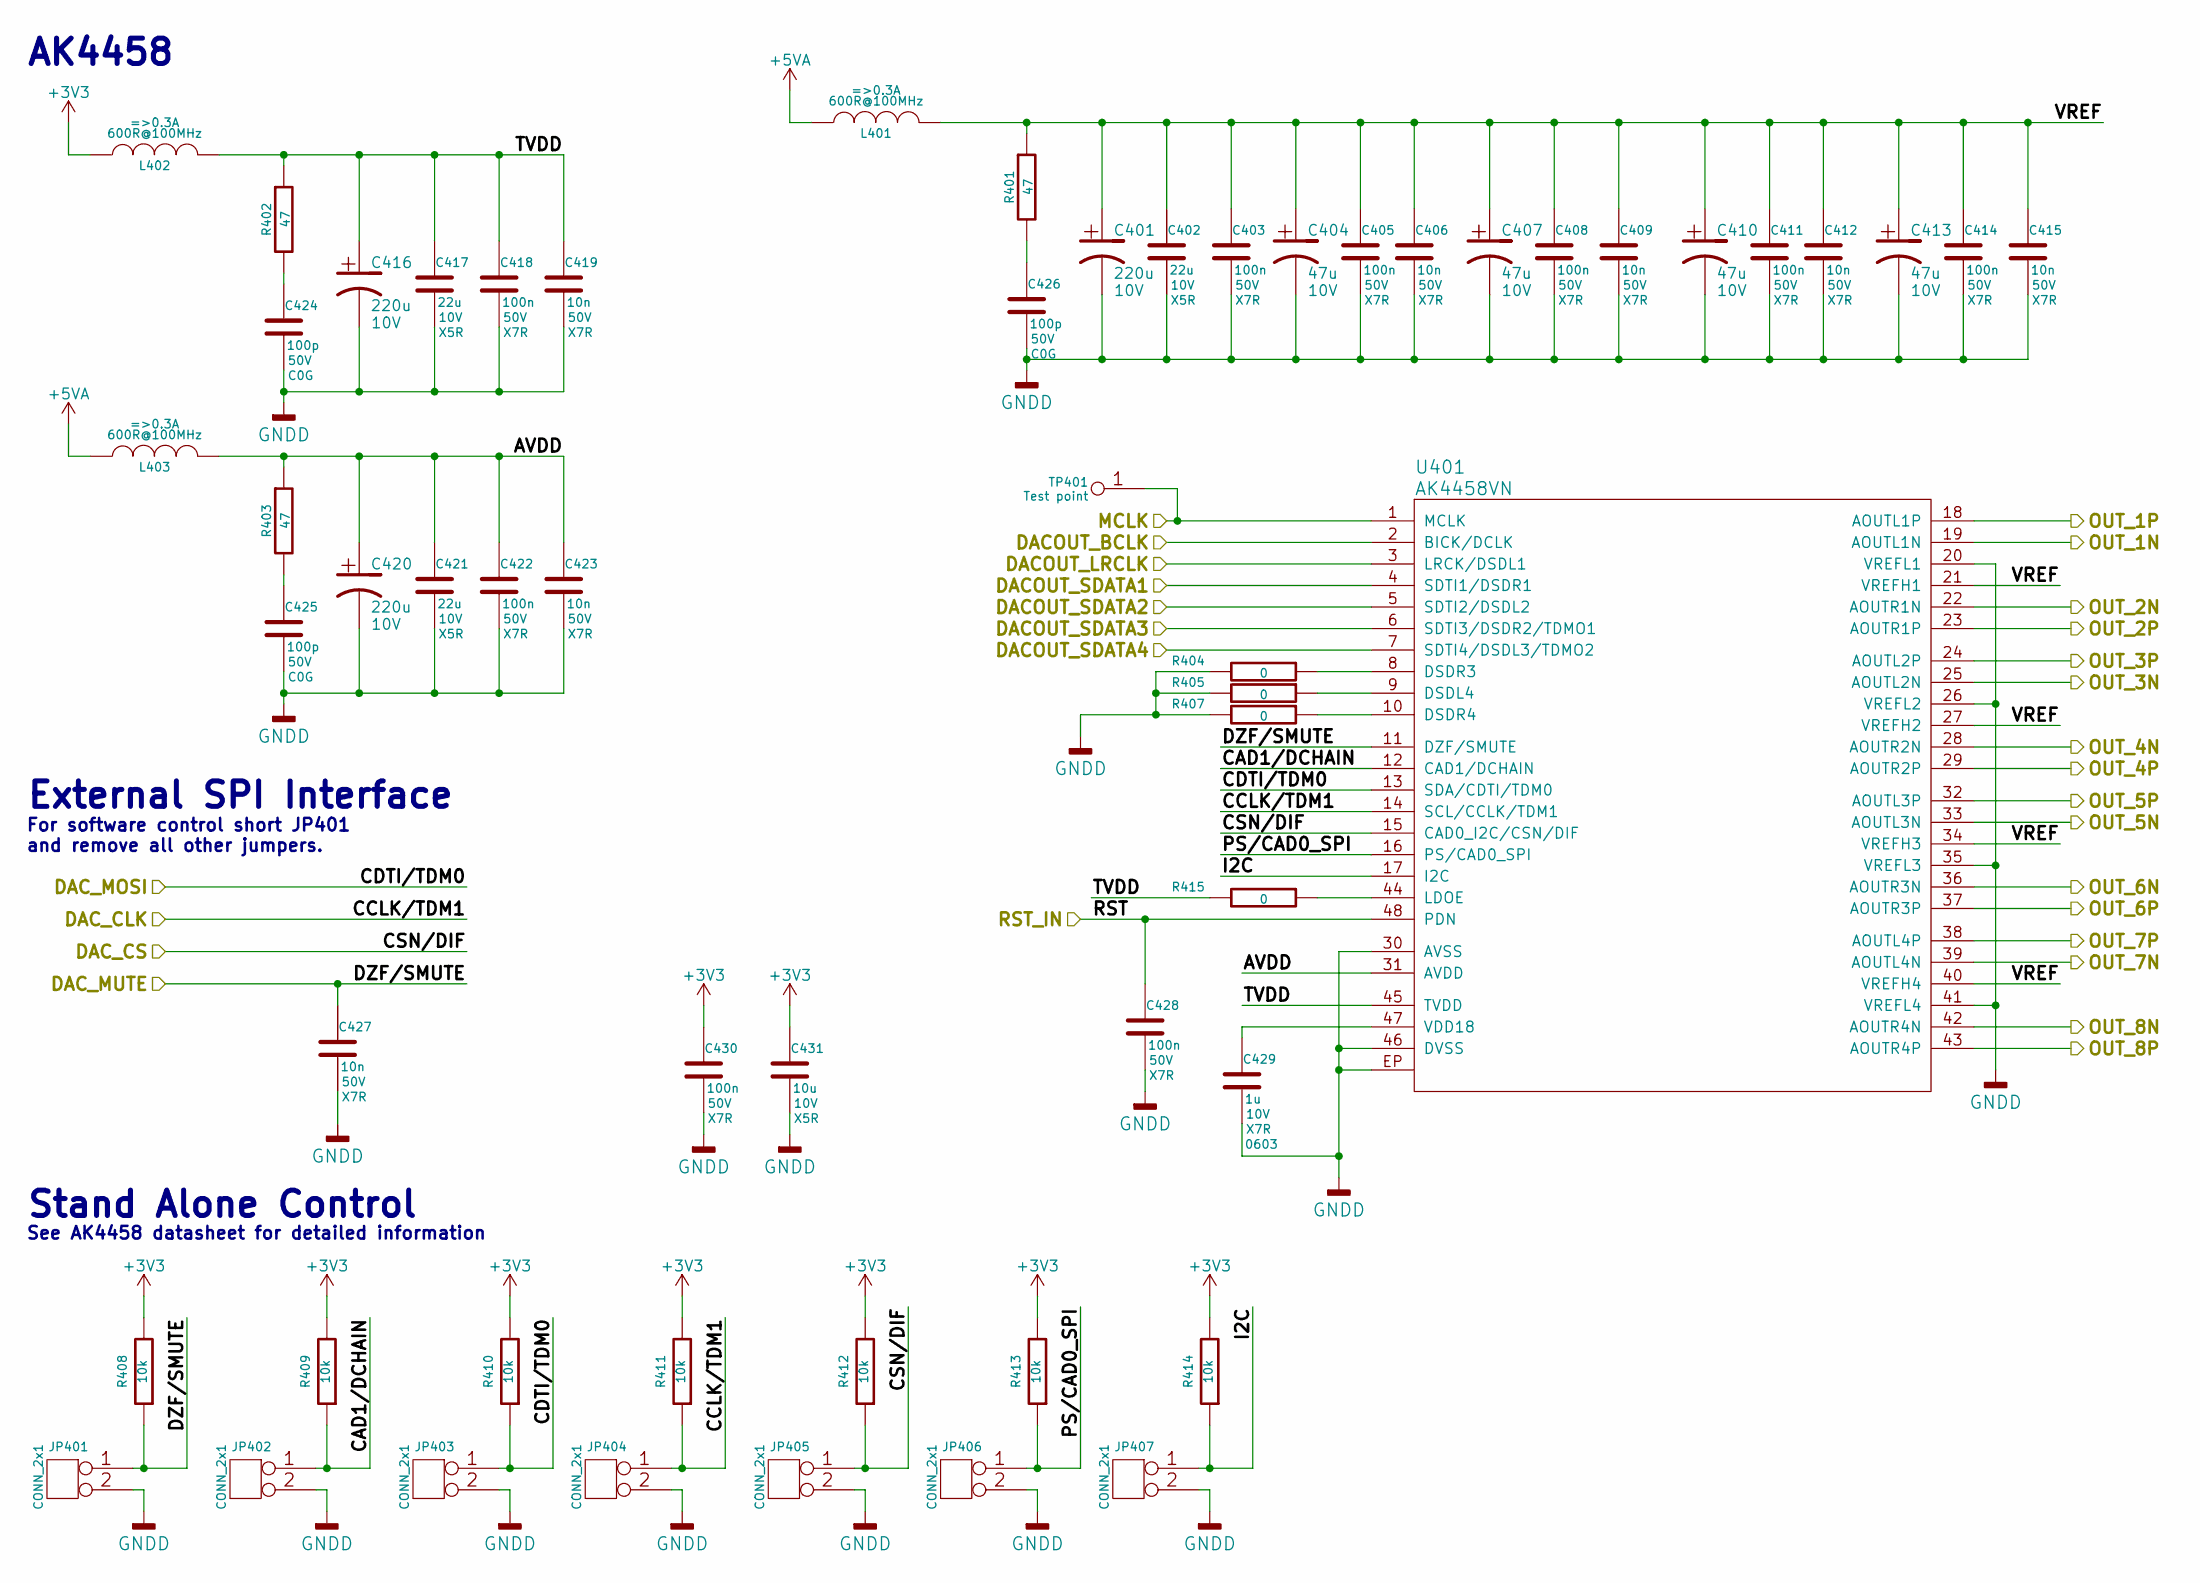
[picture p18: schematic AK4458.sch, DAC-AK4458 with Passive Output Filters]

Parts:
C401, C416, C420: 220u; CAP-TH-D6.3mmP2.5mm; Voltage 10V
C402, C417, C421: 22u; SMD-0805; Voltage 10V; Tolerance 20%
C403, C405, C408, C411, C414, C418, C422, C428, C430: 100n; SMD-0805; Voltage 50V; Tolerance 10%
C404, C407, C410, C413: 47u; CAP-TH-D6.3mmP2.5mm; Voltage 10V
C406, C409, C412, C415, C419, C423, C427: 10n; SMD-0805; Voltage 50V; Tolerance 10%
C424, C425, C426: 100p; SMD-0805; Voltage 50V; Tolerance 5%
C429: 1u; SMD-0603; Voltage 10V; Tolerance 10%
C431: 10u; SMD-0805; Voltage 10V; Tolerance 20%
JP401, JP402, JP403, JP404, JP405, JP406, JP407: CONN_2x1; CONN_SIL_2_1MM
L401, L402, L403: 600R@100MHz; SMD-0805
R401, R402, R403: 47; SMD-0805; Tolerance 1%
R404, R405, R407, R415: 0; SMD-0805; Tolerance 1%
R408, R409, R410, R411, R412, R413, R414: 10k; SMD-0805; Tolerance 1%
TP401: Test point; TP-1mm
U401: AK4458VN; IC_QFN_48_5.1mmpad_HF_HS

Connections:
+3V3: C430.1, C431.1, L402.1, R408.2, R409.2, R410.2, R411.2, R412.2, R413.2, R414.2; also elsewhere on the board
+5VA: L401.1, L403.1; also elsewhere on the board
/AK4458/AVDD: C420.1, C421.1, C422.1, C423.1, L403.2, R403.1, U401.31 (AVDD)
/AK4458/CAD1/DCHAIN: JP402.1, R409.1, U401.12 (CAD1/DCHAIN)
/AK4458/I2C: JP407.1, R414.1, U401.17 (I2C)
/AK4458/OUT_1P: U401.18 (AOUTL1P); also elsewhere on the board
/AK4458/OUT_2P: U401.23 (AOUTR1P); also elsewhere on the board
/AK4458/OUT_3P: U401.24 (AOUTL2P); also elsewhere on the board
/AK4458/OUT_4P: U401.29 (AOUTR2P); also elsewhere on the board
/AK4458/OUT_5P: U401.32 (AOUTL3P); also elsewhere on the board
/AK4458/OUT_6P: U401.37 (AOUTR3P); also elsewhere on the board
/AK4458/OUT_7P: U401.38 (AOUTL4P); also elsewhere on the board
/AK4458/OUT_8P: U401.43 (AOUTR4P); also elsewhere on the board
/AK4458/PS/CAD0_SPI: JP406.1, R413.1, U401.16 (PS/CAD0_SPI)
/AK4458/TVDD: C416.1, C417.1, C418.1, C419.1, L402.2, R402.1, R415.2, U401.45 (TVDD)
/AK4458/VREF: C401.1, C402.1, C403.1, C404.1, C405.1, C406.1, C407.1, C408.1, C409.1, C410.1, C411.1, C412.1, C413.1, C414.1, C415.1, L401.2, R401.1, U401.21 (VREFH1), U401.27 (VREFH2), U401.34 (VREFH3), U401.40 (VREFH4)
/AnaloguePassiveFilters/N1: U401.19 (AOUTL1N); also elsewhere on the board
/AnaloguePassiveFilters/N2: U401.22 (AOUTR1N); also elsewhere on the board
/AnaloguePassiveFilters/N3: U401.25 (AOUTL2N); also elsewhere on the board
/AnaloguePassiveFilters/N4: U401.28 (AOUTR2N); also elsewhere on the board
/AnaloguePassiveFilters/N5: U401.33 (AOUTL3N); also elsewhere on the board
/AnaloguePassiveFilters/N6: U401.36 (AOUTR3N); also elsewhere on the board
/AnaloguePassiveFilters/N7: U401.39 (AOUTL4N); also elsewhere on the board
/AnaloguePassiveFilters/N8: U401.42 (AOUTR4N); also elsewhere on the board
/BCLK: U401.2 (BICK/DCLK); also elsewhere on the board
/GLB_RST: C428.1, U401.48 (PDN); also elsewhere on the board
/LRCLK: U401.3 (LRCK/DSDL1); also elsewhere on the board
/MCLK: TP401.1, U401.1 (MCLK); also elsewhere on the board
/MUTE: C427.1, JP401.1, R408.1, U401.11 (DZF/SMUTE); also elsewhere on the board
/SDATA1: U401.4 (SDTI1/DSDR1); also elsewhere on the board
/SDATA2: U401.5 (SDTI2/DSDL2); also elsewhere on the board
/SDATA3: U401.6 (SDTI3/DSDR2/TDMO1); also elsewhere on the board
/SDATA4: U401.7 (SDTI4/DSDL3/TDMO2); also elsewhere on the board
/SPI_CLK: JP404.1, R411.1, U401.14 (SCL/CCLK/TDM1); also elsewhere on the board
/SPI_CS: JP405.1, R412.1, U401.15 (CAD0_I2C/CSN/DIF); also elsewhere on the board
/SPI_MOSI: JP403.1, R410.1, U401.13 (SDA/CDTI/TDM0); also elsewhere on the board
GNDA: C401.2, C402.2, C403.2, C404.2, C405.2, C406.2, C407.2, C408.2, C409.2, C410.2, C411.2, C412.2, C413.2, C414.2, C415.2, C416.2, C417.2, C418.2, C419.2, C420.2, C421.2, C422.2, C423.2, C424.2, C425.2, C426.2, C427.2, C428.2, C429.2, C430.2, C431.2, JP401.2, JP402.2, JP403.2, JP404.2, JP405.2, JP406.2, JP407.2, R404.2, R405.2, R407.2, U401.20 (VREFL1), U401.26 (VREFL2), U401.30 (AVSS), U401.35 (VREFL3), U401.41 (VREFL4), U401.46 (DVSS), U401.EP; also elsewhere on the board
unnamed: C424.1, R402.2
unnamed: C425.1, R403.2
unnamed: C426.1, R401.2
unnamed: C429.1, U401.47 (VDD18)
unnamed: R404.1, U401.8 (DSDR3)
unnamed: R405.1, U401.9 (DSDL4)
unnamed: R407.1, U401.10 (DSDR4)
unnamed: R415.1, U401.44 (LDOE)

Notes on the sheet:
External SPI Interface
Stand Alone Control
For software control short JP401 and remove all other jumpers.
AK4458
See AK4458 datasheet for detailed information

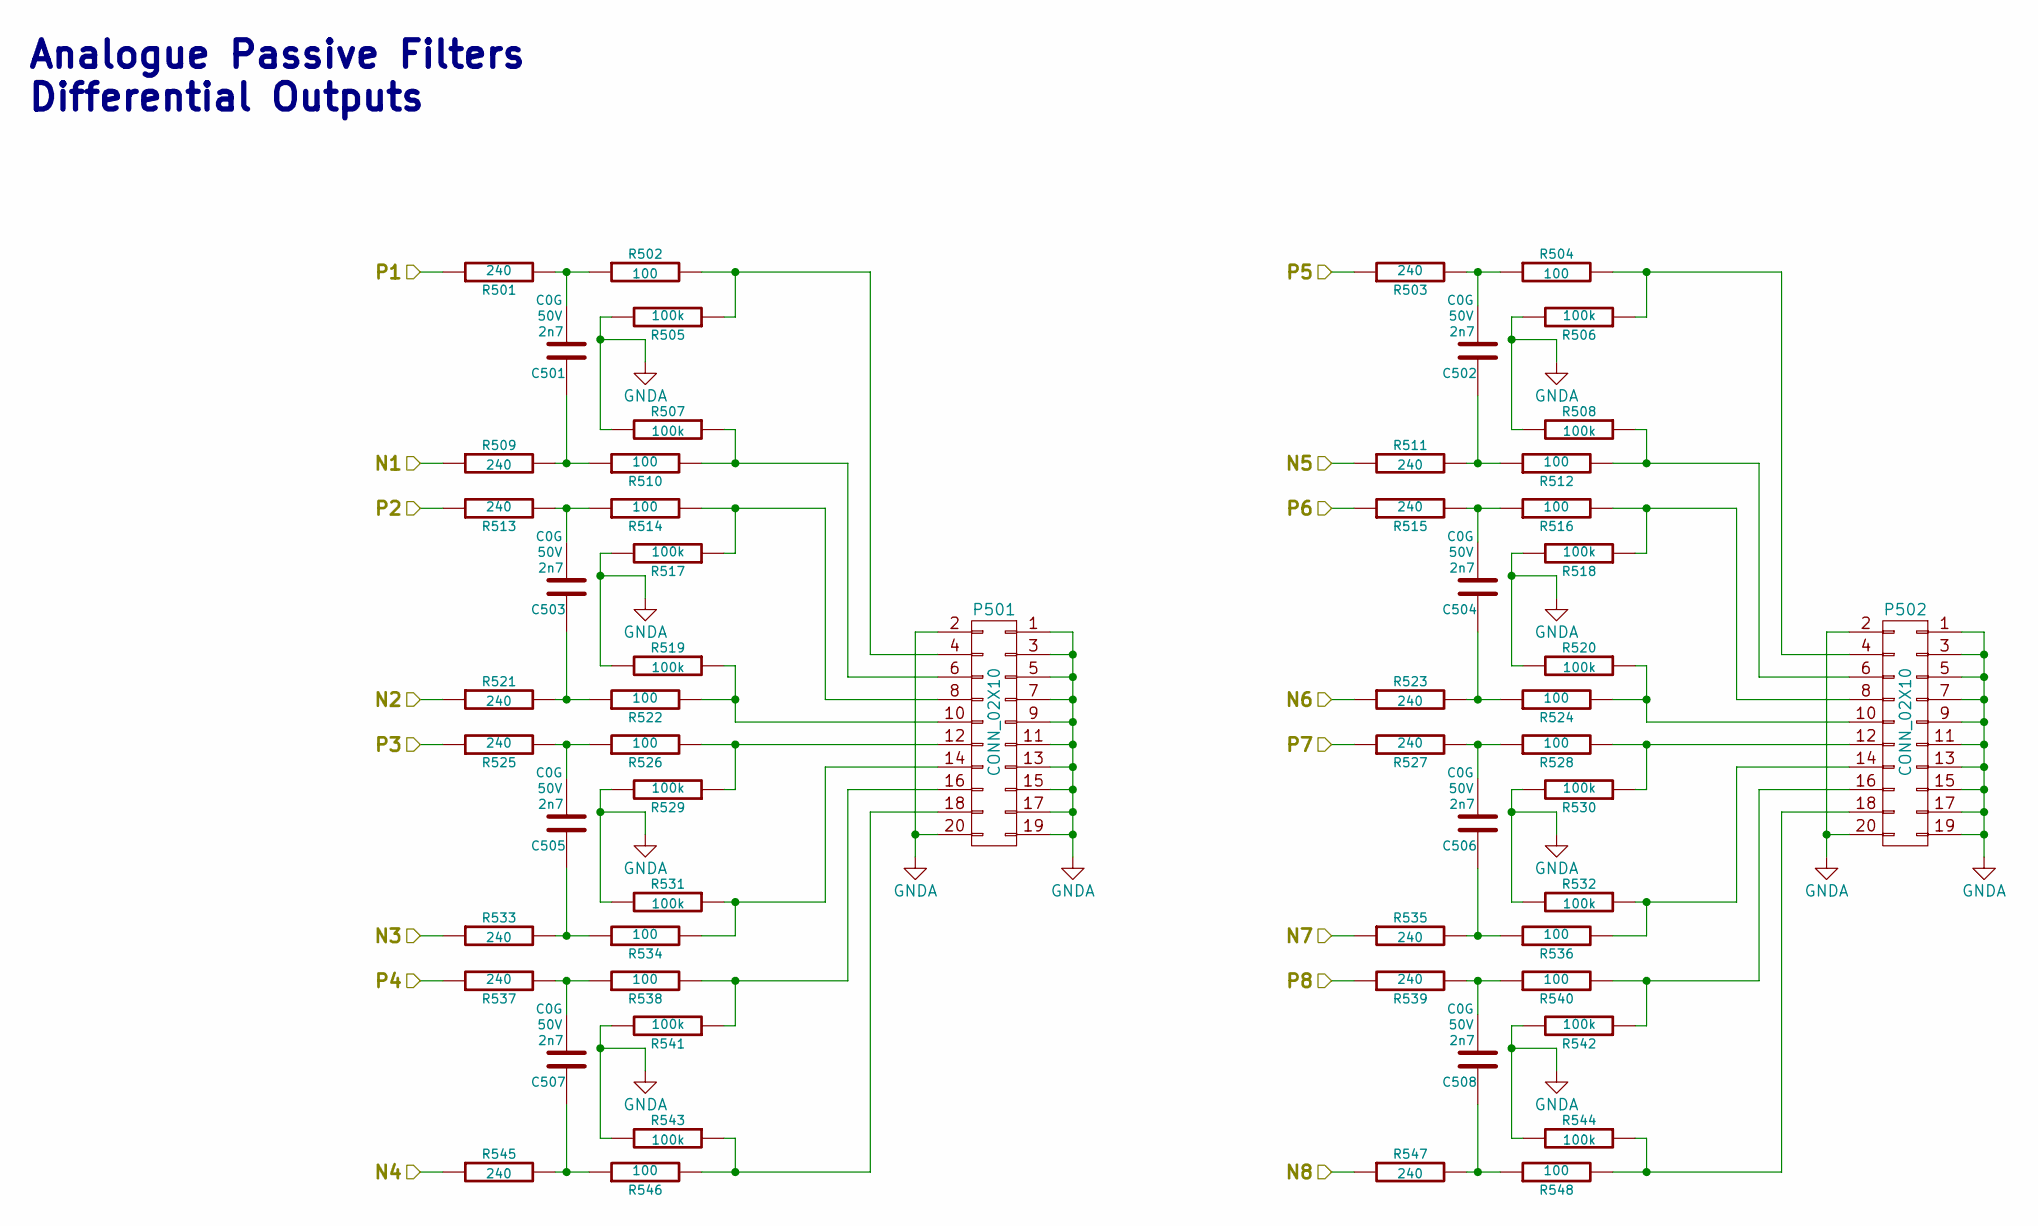
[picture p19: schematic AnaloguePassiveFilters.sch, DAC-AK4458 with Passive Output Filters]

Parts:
C501, C502, C503, C504, C505, C506, C507, C508: 2n7; SMD-0805; Voltage 50V; Tolerance 5%
P501, P502: CONN_02X10; CONN_DIL_2X10_BOX_1MM
R501, R503, R509, R511, R513, R515, R521, R523, R525, R527, R533, R535, R537, R539, R545, R547: 240; SMD-1206; Tolerance 1%
R502, R504, R510, R512, R514, R516, R522, R524, R526, R528, R534, R536, R538, R540, R546, R548: 100; SMD-1206; Tolerance 1%
R505, R506, R507, R508, R517, R518, R519, R520, R529, R530, R531, R532, R541, R542, R543, R544: 100k; SMD-1206; Tolerance 1%

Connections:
/AK4458/OUT_1P: R501.1; also elsewhere on the board
/AK4458/OUT_2P: R513.1; also elsewhere on the board
/AK4458/OUT_3P: R525.1; also elsewhere on the board
/AK4458/OUT_4P: R537.1; also elsewhere on the board
/AK4458/OUT_5P: R503.1; also elsewhere on the board
/AK4458/OUT_6P: R515.1; also elsewhere on the board
/AK4458/OUT_7P: R527.1; also elsewhere on the board
/AK4458/OUT_8P: R539.1; also elsewhere on the board
/AnaloguePassiveFilters/N1: R509.1; also elsewhere on the board
/AnaloguePassiveFilters/N2: R521.1; also elsewhere on the board
/AnaloguePassiveFilters/N3: R533.1; also elsewhere on the board
/AnaloguePassiveFilters/N4: R545.1; also elsewhere on the board
/AnaloguePassiveFilters/N5: R511.1; also elsewhere on the board
/AnaloguePassiveFilters/N6: R523.1; also elsewhere on the board
/AnaloguePassiveFilters/N7: R535.1; also elsewhere on the board
/AnaloguePassiveFilters/N8: R547.1; also elsewhere on the board
GNDA: P501.1, P501.2, P501.3, P501.5, P501.7, P501.9, P501.11, P501.13, P501.15, P501.17, P501.19, P501.20, P502.1, P502.2, P502.3, P502.5, P502.7, P502.9, P502.11, P502.13, P502.15, P502.17, P502.19, P502.20, R505.2, R506.2, R507.2, R508.2, R517.2, R518.2, R519.2, R520.2, R529.2, R530.2, R531.2, R532.2, R541.2, R542.2, R543.2, R544.2; also elsewhere on the board
unnamed: C501.1, R509.2, R510.1
unnamed: C501.2, R501.2, R502.1
unnamed: C502.1, R511.2, R512.1
unnamed: C502.2, R503.2, R504.1
unnamed: C503.1, R521.2, R522.1
unnamed: C503.2, R513.2, R514.1
unnamed: C504.1, R523.2, R524.1
unnamed: C504.2, R515.2, R516.1
unnamed: C505.1, R533.2, R534.1
unnamed: C505.2, R525.2, R526.1
unnamed: C506.1, R535.2, R536.1
unnamed: C506.2, R527.2, R528.1
unnamed: C507.1, R545.2, R546.1
unnamed: C507.2, R537.2, R538.1
unnamed: C508.1, R547.2, R548.1
unnamed: C508.2, R539.2, R540.1
unnamed: P501.4, R502.2, R505.1
unnamed: P501.6, R507.1, R510.2
unnamed: P501.8, R514.2, R517.1
unnamed: P501.10, R519.1, R522.2
unnamed: P501.12, R526.2, R529.1
unnamed: P501.14, R531.1, R534.2
unnamed: P501.16, R538.2, R541.1
unnamed: P501.18, R543.1, R546.2
unnamed: P502.4, R504.2, R506.1
unnamed: P502.6, R508.1, R512.2
unnamed: P502.8, R516.2, R518.1
unnamed: P502.10, R520.1, R524.2
unnamed: P502.12, R528.2, R530.1
unnamed: P502.14, R532.1, R536.2
unnamed: P502.16, R540.2, R542.1
unnamed: P502.18, R544.1, R548.2

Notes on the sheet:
Analogue Passive Filters Differential Outputs

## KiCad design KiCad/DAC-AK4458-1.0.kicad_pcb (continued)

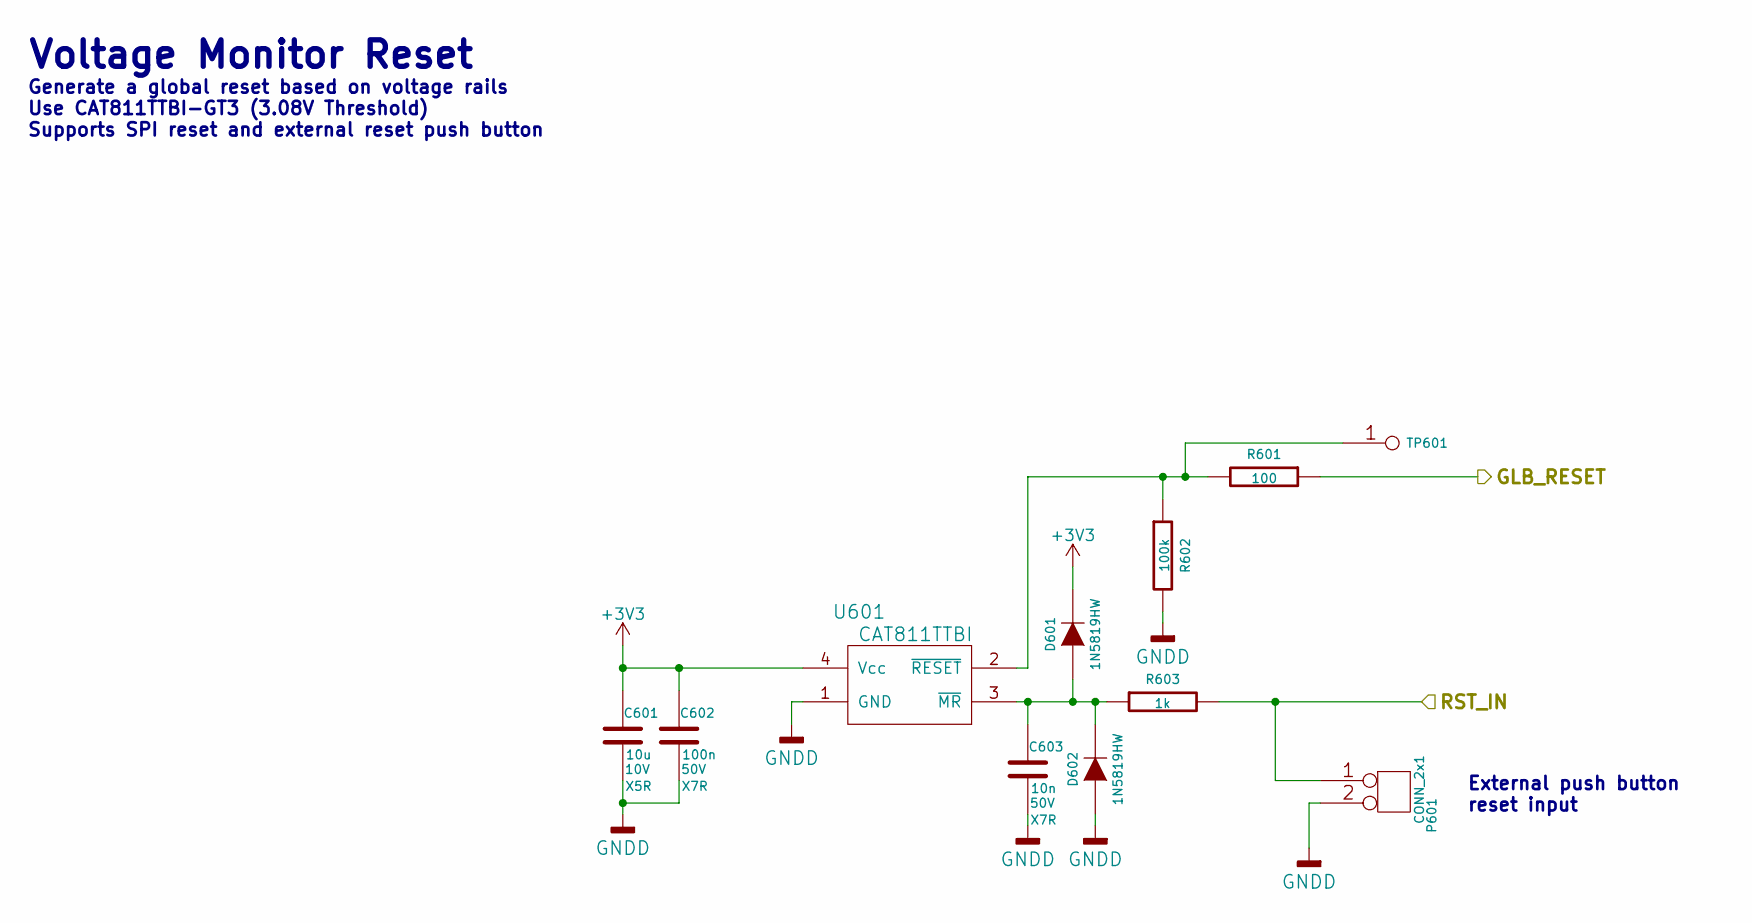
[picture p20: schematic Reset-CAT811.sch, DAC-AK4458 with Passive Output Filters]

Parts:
C601: 10u; SMD-0805; Voltage 10V; Tolerance 20%
C602: 100n; SMD-0805; Voltage 50V; Tolerance 10%
C603: 10n; SMD-0805; Voltage 50V; Tolerance 10%
D601, D602: 1N5819HW; DIODE-SOD-123
P601: CONN_2x1; CONN_SIL_2_1MM
R601: 100; SMD-0805; Tolerance 1%
R602: 100k; SMD-0805; Tolerance 1%
R603: 1k; SMD-0805; Tolerance 1%
TP601: PIN; TP-2mm
U601: CAT811TTBI; IC-SOT143

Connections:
+3V3: C601.1, C602.1, D601.2 (K), U601.4 (Vcc); also elsewhere on the board
/GLB_RST: R601.1; also elsewhere on the board
/Reset-CAT811/RST_IN: P601.1, R603.2; also elsewhere on the board
GNDA: C601.2, C602.2, C603.2, D602.1 (A), P601.2, R602.2, U601.1 (GND); also elsewhere on the board
unnamed: C603.1, D601.1 (A), D602.2 (K), R603.1, U601.3 (~MR)
unnamed: R601.2, R602.1, TP601.1, U601.2 (~RESET)

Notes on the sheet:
Generate a global reset based on voltage rails Use CAT811TTBI−GT3 (3.08V Threshold) Supports SPI reset and external reset push button
Voltage Monitor Reset
External push button reset input

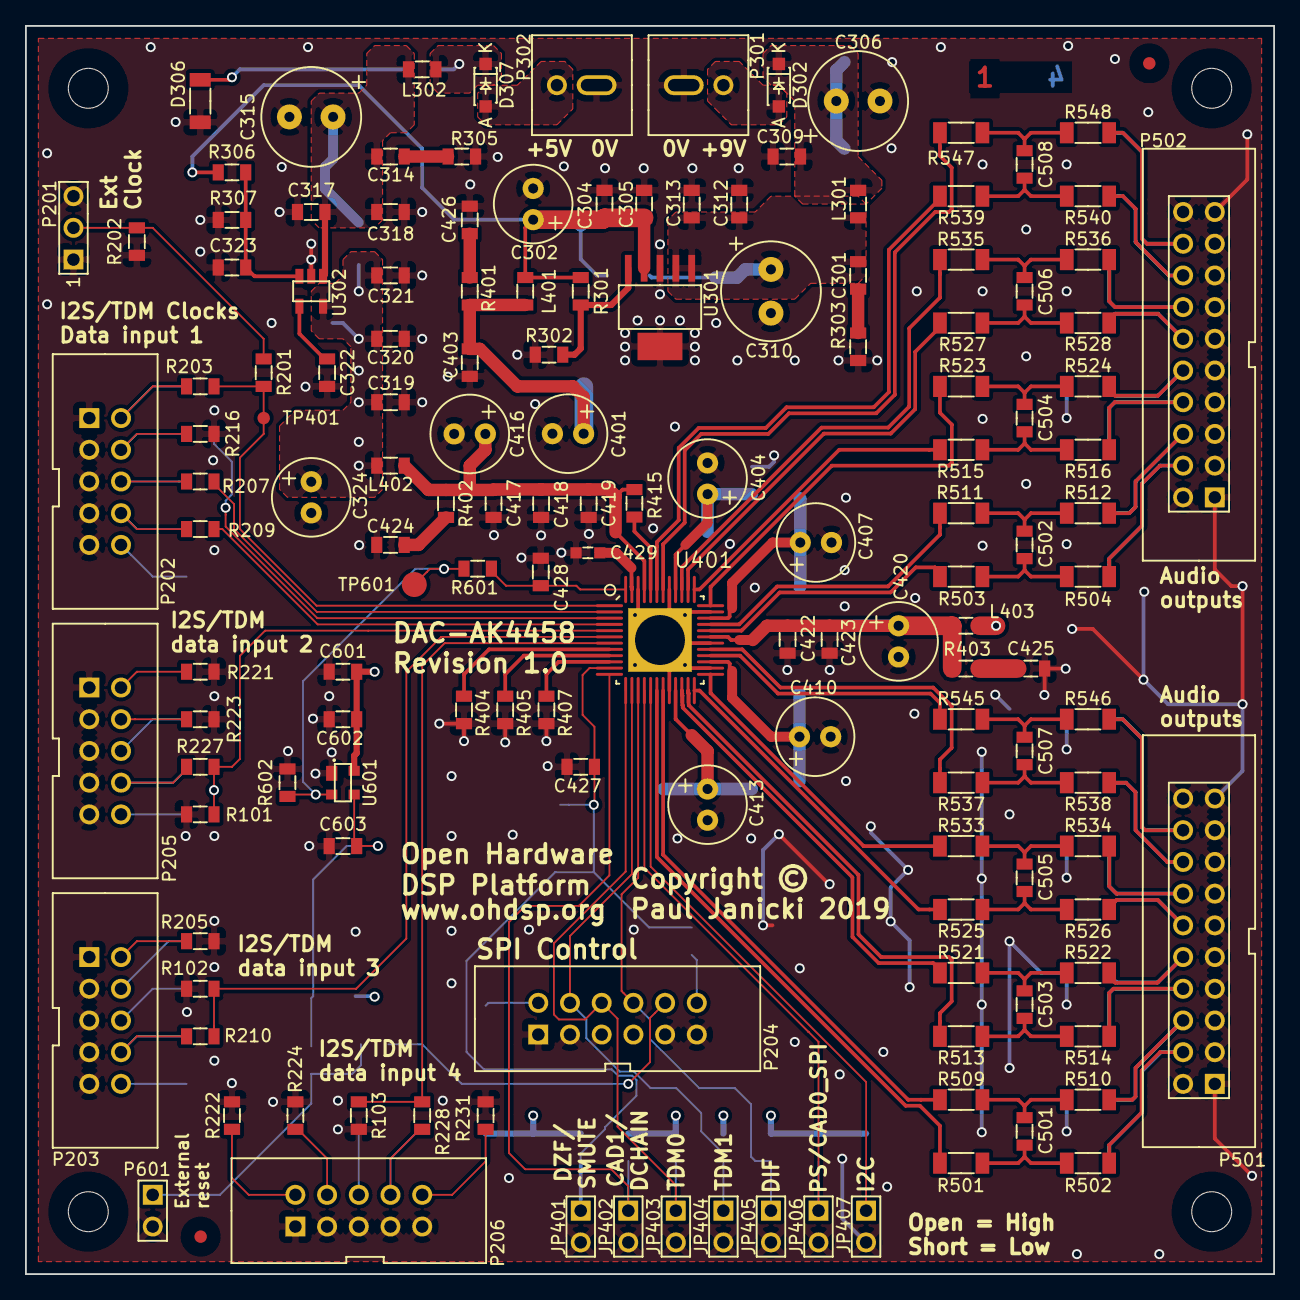
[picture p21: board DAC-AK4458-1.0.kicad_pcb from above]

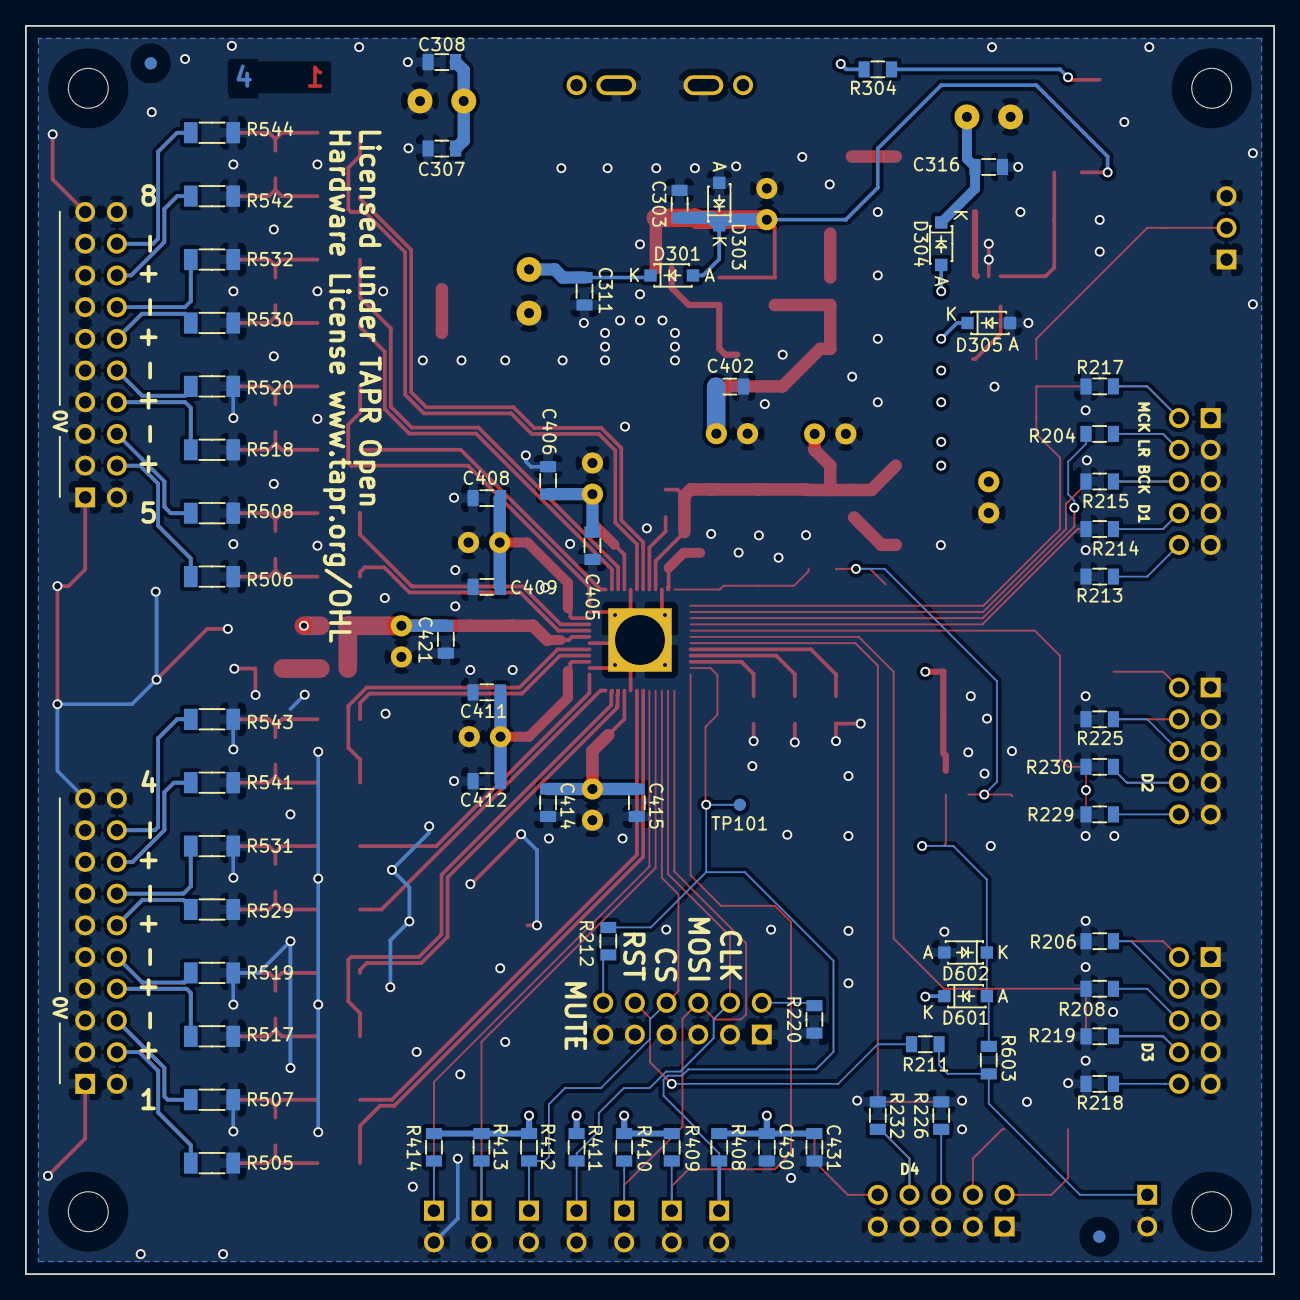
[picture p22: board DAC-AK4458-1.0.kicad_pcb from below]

Board: 4 copper layers, 100.0 x 100.0 mm, 220 parts (68 on the bottom side), 116 nets.

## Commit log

2019-04-03 DAC-AK4458-1.0
    DAC-AK4458-1.0
    [AK4458.sch, AnaloguePassiveFilters.sch, Connectors.sch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]
2019-04-03 DAC-AK4458-1.0
    Fix gerber front mask error
    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
    [DAC-AK4458-1.0-B_Cu.gbl, DAC-AK4458-1.0-B_Mask.gbs, DAC-AK4458-1.0-B_Paste.gbp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]

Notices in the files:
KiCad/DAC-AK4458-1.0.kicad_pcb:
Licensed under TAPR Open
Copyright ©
